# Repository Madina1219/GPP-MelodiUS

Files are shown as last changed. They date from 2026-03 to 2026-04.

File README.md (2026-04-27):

# MelodiUS

## Twin Piano Experience: An IoT-Connected Musical Instrument

**CASA0021: Group Prototype + Pitch**  
**Connected Environments - Group 6**  
**University College London (CASA) | 2025-2026**

| Team Member | Role |
|---|---|
| Madina Diallo | Project Manager |
| Xintong Shao | Enclosure Design and Aesthetics |
| Lizi Wang | Hardware & Software Developer |
| Ananya Jagadeesh Kedlaya | Software & Connectivity Lead |
| All Team Members | User Testing |

**GitHub repository:** <https://github.com/Madina1219/GPP-MelodiUS>  
**Word count:** approximately 2,000 words, excluding cover page, in-text citations and reference list  
**AI use statement:** AI tools were used to support structural review and refinement of phrasing. All technical content, design decisions, code, and analysis are the original work of the team.

---

## Abstract

MelodiUS is a pair of IoT-connected mini pianos designed to enable synchronised musical interaction between two users across any physical distance. When a key is pressed on Piano A, the corresponding key on Piano B lights up via LED feedback and plays the same note through I2S audio output, creating a mirrored experience in near real time. Communication is handled through MQTT over a local Wi-Fi network, with solenoid-based mechanical actuation identified as a future development path. This report documents the design rationale, technical development, iterative prototyping, and the broader Connected Environments context of the project, and outlines opportunities for further work.

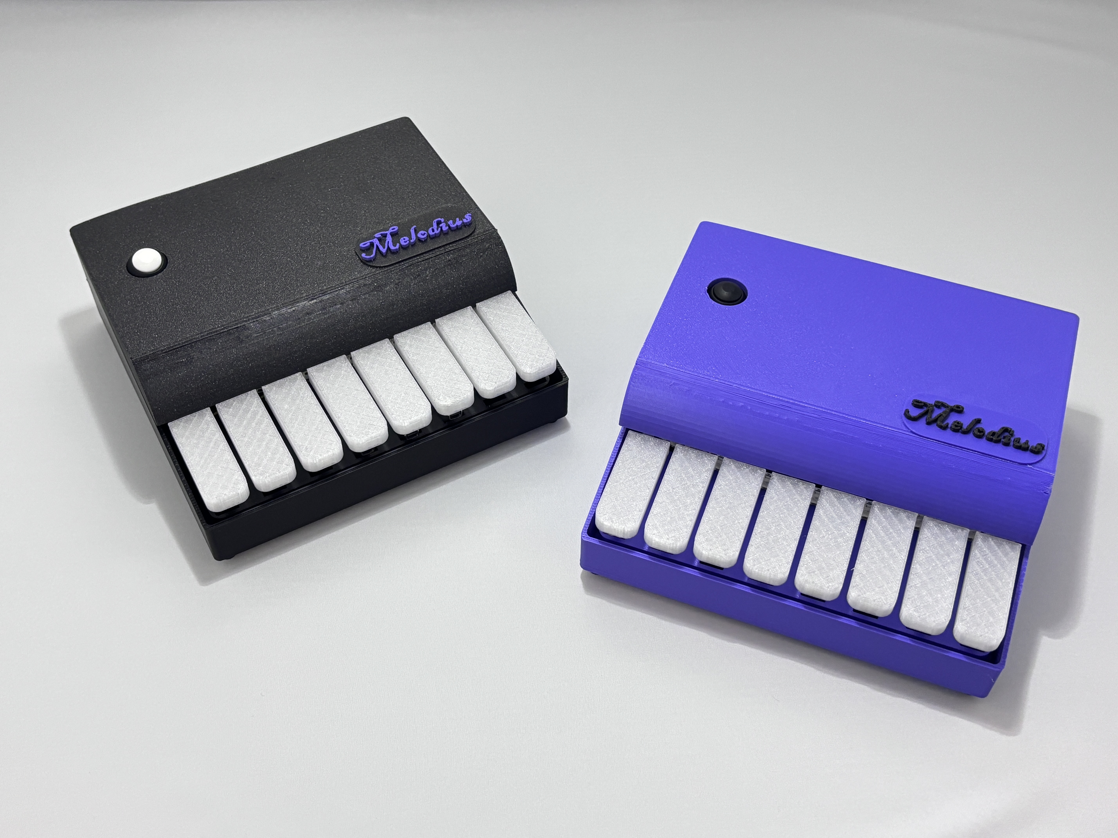
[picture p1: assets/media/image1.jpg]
Figure 1: The two finished MelodiUS units - a paired connected musical instrument.


*Figure 1: The two finished MelodiUS units - a paired connected musical instrument.*

---

## Table of Contents

- [1. Problem Identification and Motivation](#1-problem-identification-and-motivation)
  - [1.1 The Problem: Distance and Musical Connection](#11-the-problem-distance-and-musical-connection)
  - [1.2 Target Users and Scenarios](#12-target-users-and-scenarios)
  - [1.3 Context Within Connected Environments Research](#13-context-within-connected-environments-research)
- [2. Development of the Prototype and Design Iterations](#2-development-of-the-prototype-and-design-iterations)
  - [2.1 Initial Concept and Design Brief](#21-initial-concept-and-design-brief)
  - [2.2 Hardware Architecture](#22-hardware-architecture)
  - [2.3 Firmware Development](#23-firmware-development)
  - [2.4 Enclosure Design and Iterations](#24-enclosure-design-and-iterations)
  - [2.5 Connectivity and Software Stack](#25-connectivity-and-software-stack)
  - [2.6 User Testing and Evaluation](#26-user-testing-and-evaluation)
- [3. Production Cost and Sustainability](#3-production-cost-and-sustainability)
- [4. Future Improvements](#4-future-improvements)
- [5. Conclusion](#5-conclusion)
- [6. References](#6-references)

---

## 1. Problem Identification and Motivation

### 1.1 The Problem: Distance and Musical Connection

Music has long served as one of the most powerful vehicles for human connection. Yet remote work, long-distance relationships, and geographically distributed families mean that shared musical moments, playing together, learning together, or simply being present in the same musical space, are increasingly difficult to achieve. Existing solutions fall short. Video calls introduce audio-visual latency that makes synchronised playing practically impossible, while online music collaboration tools remain largely screen-based and disembodied, lacking the tactile presence of a shared instrument.

MelodiUS addresses this gap directly by exploring how two people, regardless of physical distance, can share the experience of playing an instrument together with genuine physical feedback and minimal latency, without requiring specialist audio infrastructure. The proposed answer is a pair of IoT-connected physical piano units that mirror key presses, LED responses, and, in future iterations, mechanical actuation in near real time using the MQTT messaging protocol over standard Wi-Fi.

### 1.2 Target Users and Scenarios

MelodiUS is designed for four user groups. First, distant families, for example, a grandparent playing a lullaby/nursery rhyme in Manchester while their grandchild hears every key press live in Paris. Second, couples in long-distance relationships who wish to share a nightly duet. Third, friends who grew up playing together but now live in different cities. Fourth, piano teachers and students, where a tutor in London can demonstrate fingering on a student's piano in Liverpool in real time, going beyond what screen sharing alone offers.

A central design decision was approachability. The pianos are compact, 3D-printed, and require no specialist technical knowledge: the user powers on the unit, connects to Wi-Fi through a captive web portal, and the two devices synchronise automatically through a shared MQTT broker. This deliberate simplicity lowers the barrier to entry while demonstrating sophisticated IoT connectivity underneath.

### 1.3 Context Within Connected Environments Research

MelodiUS sits within a rich lineage of research at the intersection of the Internet of Things, tangible computing, and human-computer interaction. Ishii and Ullmer (1997, pp. 234–241) argued that embedding computation in everyday objects produces more intuitive, embodied interaction; MelodiUS operationalises this principle directly, with the keys forming the interface and the LEDs and audio output forming tangible representations of networked data.

The project also draws on the calm technology tradition (Weiser and Brown, 1996, pp. 75–85), in which connected devices communicate peripherally without demanding sustained visual attention. Light and sound function here as ambient cues of remote presence rather than as primary information channels. The use of MQTT, a lightweight publish-subscribe protocol widely adopted in IoT deployments, is consistent with established practice for constrained networks (Banks and Gupta, 2014).

The project further aligns with affective computing, where connected devices mediate emotional states across distance rather than simply transmitting data (Picard, 1997). Within the specific domain of networked music performance (Rottondi et al., 2016), MelodiUS departs from high-fidelity audio streaming by transmitting discrete key-press events instead. This deliberate simplification reduces latency and hardware requirements while preserving the essence of shared musical play, positioning the project as a consumer-oriented interpretation of research-grade network music performance.

---

## 2. Development of the Prototype and Design Iterations

### 2.1 Initial Concept and Design Brief

The project responded to the Connected Places: Connected Ambient Devices Across the Miles brief, which required two independent yet linked devices capable of communicating information in a simple, glanceable, low-effort manner. Early ideation explored environmental sensing and community-based ambient systems, but the team identified an opportunity to reinterpret ambient connectivity through emotional, human-centred interaction. Music emerged as a uniquely powerful medium: it is universal, naturally expressive, and well-suited to glanceable, low-data communication.

The original vision involved full mechanical key actuation using solenoids to physically replicate remote presses. Component lead-times and the complexity of driving eight solenoids per device within a compact, battery-powered enclosure made this infeasible within the available timeframe. The team pivoted to LED feedback paired with I2S audio output, which preserves the core ambient experience of real-time perceptible connection while ensuring technical reliability. Solenoid actuation remains a defined future enhancement. The final brief settled on three requirements: near-zero perceived latency, accessible and reproducible components, and a high-quality physical form factor.

### 2.2 Hardware Architecture

Each device is built around an ESP32 microcontroller and integrates physical input, audio output, and visual feedback into a single self-contained unit. At the input layer, eight tactile push buttons are mapped to GPIO pins and represent the notes C4 to C5. Physical buttons were chosen over capacitive or screen-based alternatives because tactile feedback is fundamental to a musical interaction and lowers the barrier for non-expert users. At the output layer, audio is generated through an I2S interface driving a MAX98357A digital amplifier and a small speaker (Integrated Espressif Systems, 2024), which replaced an earlier piezo-buzzer prototype and substantially improved tonal clarity. Visual feedback is provided by a strip of WS2812 addressable LEDs, with two LEDs allocated per key and additional LEDs reserved for system states such as Wi-Fi connectivity and configuration mode, so that the device communicates its state without needing a screen.

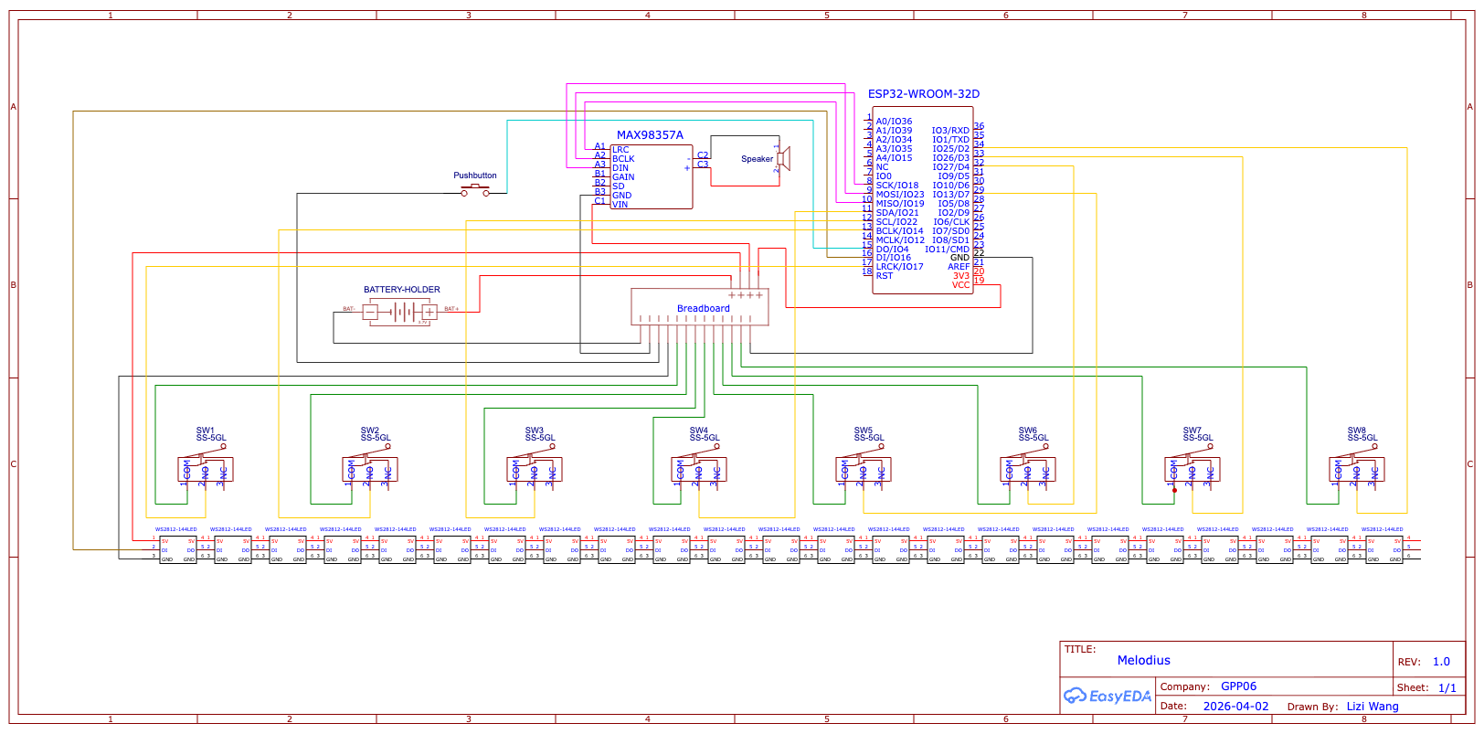
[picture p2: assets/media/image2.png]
Figure 2: Wiring diagram for a single MelodiUS unit.


*Figure 2: Wiring diagram for a single MelodiUS unit, showing ESP32, MAX98357A amplifier, push buttons, and the WS2812 LED strip.*

### 2.3 Firmware Development

Firmware development was highly iterative, illustrated in Figure 3. The first stage validated end-to-end interaction using a single key, confirming that the ESP32 could produce a perceptibly immediate response from physical input through to audio and LED output. Connectivity was then introduced through MQTT (Banks and Gupta, 2014). Rather than streaming audio, the system adopted an event-based protocol in which only key-press and key-release events are transmitted; each device reconstructs the corresponding sound and light locally. This event-driven choice was critical: it reduced bandwidth, removed the need for buffering, and made latency predictable.

The system was scaled to support all eight keys, with polyphony achieved by mixing real-time sine waves on the ESP32 (Smith, 2010). Finally, usability features were layered on top: a Wi-Fi access-point and captive web portal for first-time setup, a structured set of operational states (normal, configuration, sleep), and a deep-sleep routine that significantly improved battery life. Each iteration responded to a limitation observed in the previous one, allowing hardware, communication, and user experience to evolve in parallel.

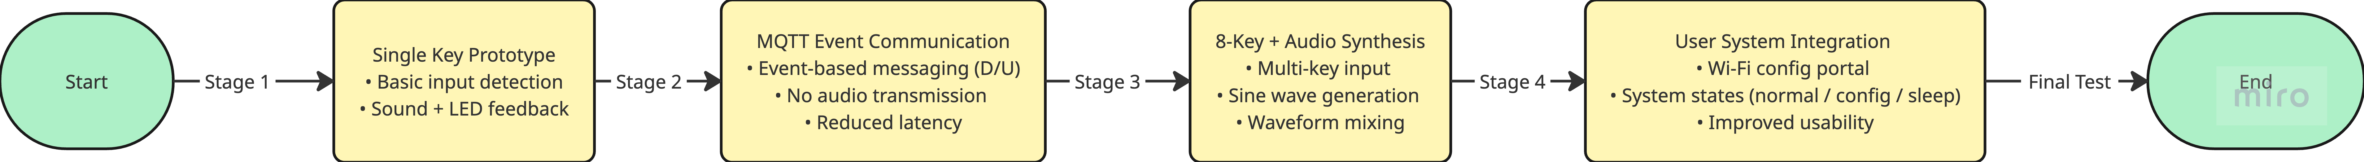
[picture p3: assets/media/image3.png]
Figure 3: Firmware evolution.


*Figure 3: Firmware evolution - from a single-key prototype, through MQTT event communication, to an eight-key polyphonic system with full user-state integration.*

### 2.4 Enclosure Design and Iterations

The enclosure was designed in Fusion 360 and 3D-printed, with three significant iterations driven by the relationships between form, manufacturability, internal layout, and usability (Weichel, Lau and Gellersen, 2013).

The first version verified the overall form, proportions, and rough internal volume. Once printed, the cavities were too tight for the wiring loom, the three top pillars intended to retain the keys were fragile and broke during installation, and the keys themselves were not properly constrained, allowing them to shift during play.

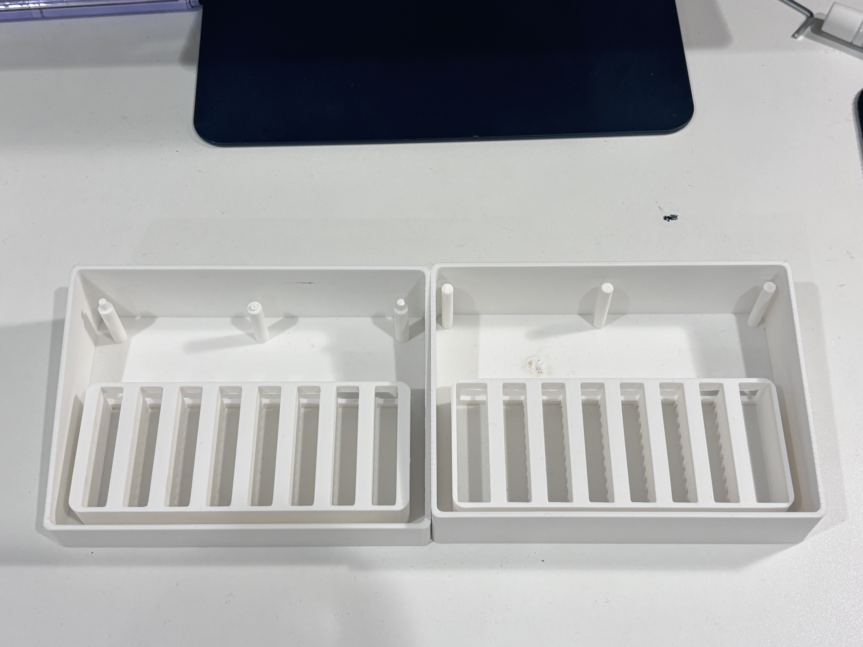
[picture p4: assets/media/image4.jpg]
Figure 4: First enclosure iteration.


*Figure 4: First enclosure iteration. Functional as a fit-check but cramped internally and structurally fragile around the key-retention pillars.*

The second version addressed these issues directly: internal volume was increased, the support pillars were widened, and dedicated holders were modelled for the ESP32 board, the battery, and the speaker. Each component now had a defined position, which simplified assembly and improved structural rigidity.

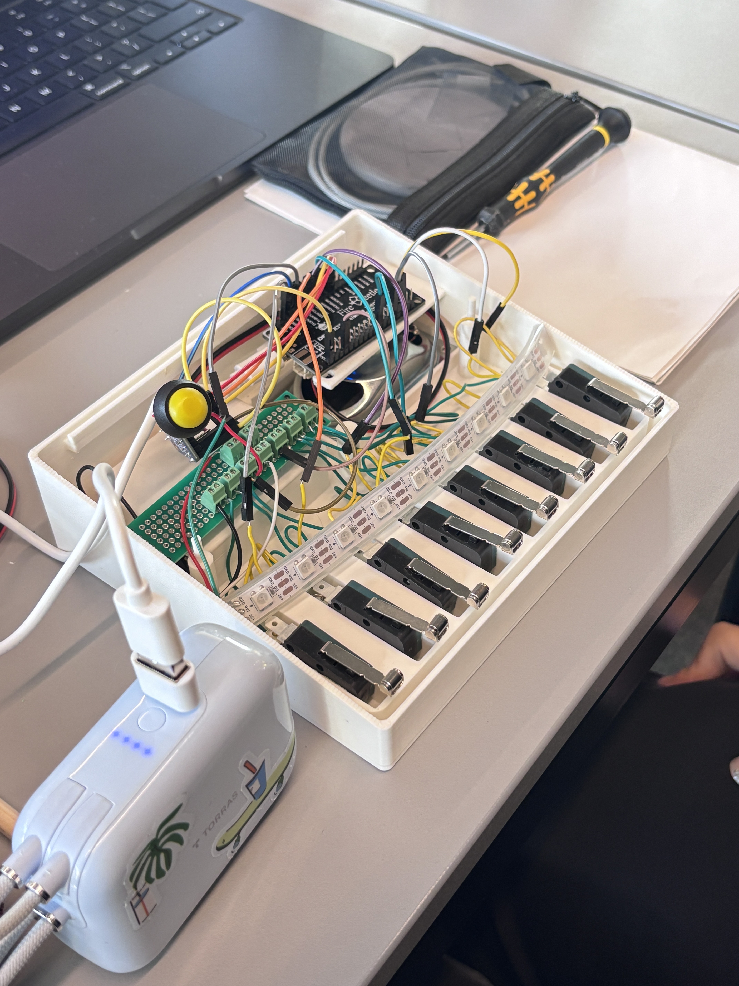
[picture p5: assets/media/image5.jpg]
Figure 5: Second enclosure iteration.


*Figure 5: Second enclosure iteration with widened pillars and dedicated component holders for the ESP32, battery, and speaker.*

The final version focused on material selection. The keys were changed from white PLA to transparent PETG so that the underlying WS2812 LEDs would illuminate the keys themselves, dramatically strengthening the visual feedback during play. A bespoke MelodiUS logo was designed and printed in a contrasting colour, and the enclosure was offered in coordinated black and purple finishes to give the product a recognisable identity and a more commercial finish.

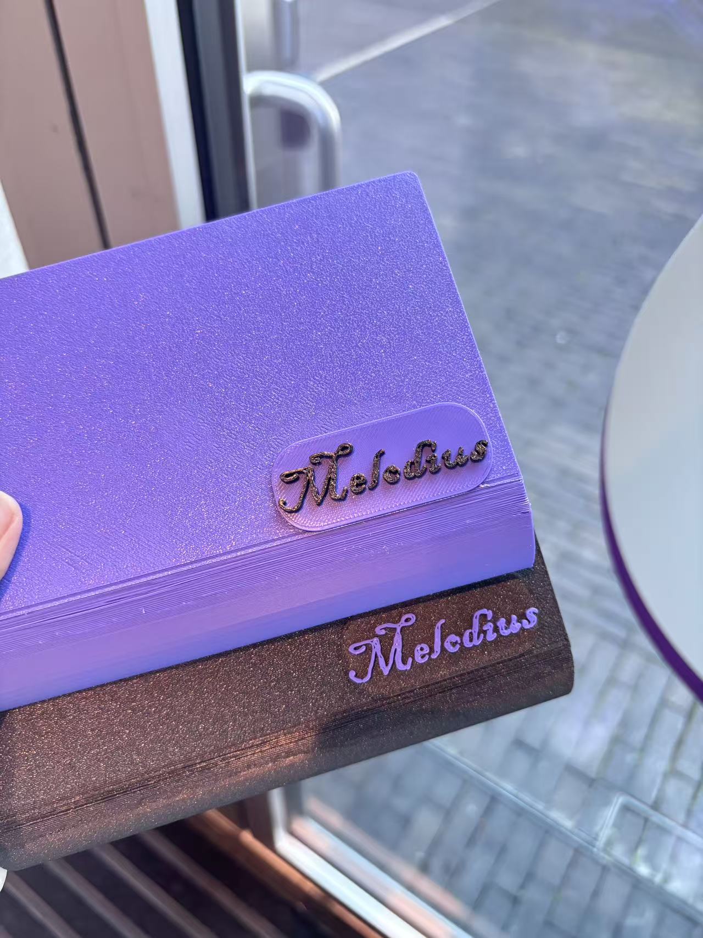
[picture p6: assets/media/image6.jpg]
Figure 6: Final enclosure detail.


*Figure 6: Final enclosure detail with custom MelodiUS logo, coordinated colourway, and matt textured finish.*

### 2.5 Connectivity and Software Stack

The system relies on a lightweight communication architecture in which two independent devices share a single MQTT broker over a local Wi-Fi network. Each key interaction is encoded as a minimal message containing the key index and a press or release flag. When a key is pressed, the device immediately produces local audio and LED feedback and simultaneously publishes the event; the other device, subscribed to the same topic, receives the message and reproduces the identical response. This event-based design avoids streaming and keeps round-trip latency low (Banks and Gupta, 2014).

The software is organised into clearly separated layers: a hardware layer for GPIO and I2S, a firmware layer for input handling, audio synthesis and LED control, a communication layer for MQTT, and a network layer for Wi-Fi management. The decoupling means that local responsiveness is not dependent on network conditions, and additional devices could in principle subscribe to the same topic without modification.

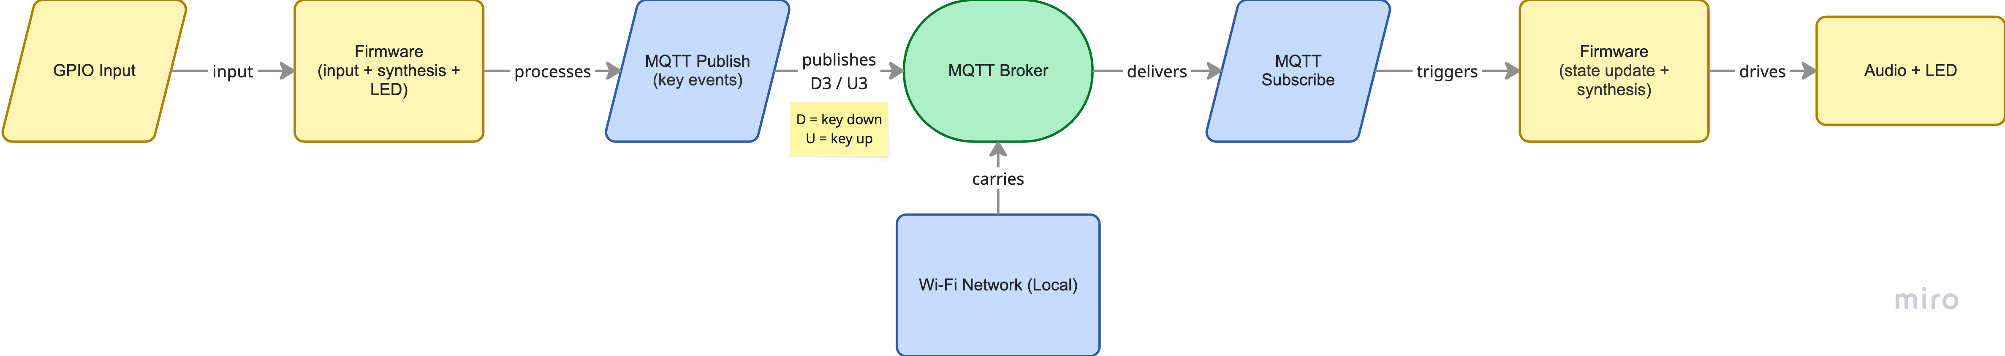
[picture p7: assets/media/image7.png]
Figure 7: System architecture.


*Figure 7: System architecture - GPIO input is processed locally and published as an MQTT event, then mirrored on the receiving device to drive identical audio and LED output.*

### 2.6 User Testing and Evaluation

- User Feedback: Testers quickly understood the LED feedback without guidance, found the audio response satisfying, and praised the refined physical design.
- Limitations: Restricted eight-key range and no velocity sensitivity.
- Functional Results: All key presses correctly triggered notes and LEDs on both devices. Latency over local Wi-Fi stayed under 500 ms, with reliable MQTT delivery.
- Iterations: Resolved Wi-Fi setup, power consumption, and false-trigger issues.
- Constraints: Tested on a single network; latency assessed perceptually.
---

## 3. Production Cost and Sustainability

**Table 1: Unit cost breakdown.**

| Component | Description | Cost (£) |
|---|---|---:|
| Hardware | ESP32 · keys · speaker · amplifier · LEDs · battery · misc. | 20-26 |
| Manufacturing | 3D-printed enclosure · assembly materials | 5-7 |
| Development | Software development · testing and iteration, amortised | 15 |
| Additional | Packaging · miscellaneous costs | 4 |
| **Total per unit** |  | **44-52** |

**Table 2: Funding and launch plan.**

| Item | Detail |
|---|---|
| Early-bird price, pair | £100 - 50% launch discount |
| Full commercial price, pair | £200 |
| Suggested retail, single | £79-99 |
| Profit margin | ~45% early bird; ~40-50% full commercial |
| Crowdfunding goal | £30,000 - covers solenoid upgrade and tooling |
| Initial batch | 200-300 units |
| Launch target | June 2026 |

Sustainability was considered at two levels. The PLA and PETG enclosure parts are biodegradable or recyclable, and the design uses standard, widely available components that can be repaired or replaced individually, avoiding the throwaway pattern of many connected consumer devices. Future revisions could replace the lithium-ion battery with a USB-C powered configuration or, as discussed in Section 4, integrate a small solar panel to reduce ongoing energy demand.

---

## 4. Future Improvements

Several improvements have been identified for future iterations of MelodiUS:

- Expanding the keyboard from eight to sixteen keys would significantly increase musical expressiveness. The MQTT protocol already supports arbitrary key indices, so the work is mostly mechanical and electrical.
- Velocity sensitivity could be added by using Hall-effect sensors with variable magnet distances, with the velocity value carried as an additional byte in the MQTT payload.
- The originally planned solenoid actuation would transform the device from a visually and aurally synchronised system into a genuinely haptic one. This requires a dedicated driver board, a more robust power supply, and careful mechanical alignment, but the emotional impact of physically moving keys would substantially strengthen the product.
- A companion mobile app could provide pairing, configuration, and a record-and-replay mode for remote teaching.
- Migrating from a local broker to a cloud-hosted MQTT broker secured with TLS and per-device authentication would extend the operating range from a single Wi-Fi network to genuinely global distances.
- Mechanical refinement (rubberised key dampers to soften the click) and energy refinement (a solar-charged battery option) would further improve the experience and sustainability profile of the product.
A couple of small things to double-check when you paste it in:

---

## 5. Conclusion

MelodiUS demonstrates that ambient, emotionally meaningful connection between distant people can be delivered through small, accessible, well-finished hardware. By transmitting discrete events rather than audio streams, the project achieves perceptibly real-time mirroring of musical play between two ESP32-based devices using nothing more than a Wi-Fi network and an MQTT broker. The iterative development process, moving from a single-key proof of concept, through firmware scaling and three enclosure revisions, to a finished pair of branded units, produced a prototype that is reliable, reproducible, and ready for further development. While limitations remain in keyboard range, expressive nuance, and operating range, each is addressed by a clearly scoped path of future work. The result is a connected musical instrument that treats distance not as an obstacle to be overcome with higher bandwidth, but as a context in which simple, well-designed signals can carry presence, intention, and shared joy.

---

## 6. References

- Banks, A. and Gupta, R. (2014) *MQTT Version 3.1.1*. OASIS Standard. Available at: <https://www.oasis-open.org/standard/mqttv3-1-1/> (Accessed: 15 April 2026).
- Espressif Systems (2024) *ESP32 Technical Reference Manual: Inter-IC Sound (I2S)*. Available at: <https://docs.espressif.com/projects/esp-idf/en/release-v4.4/esp32/api-reference/peripherals/i2s.html> (Accessed: 15 April 2026).
- HiveMQ (2023) *MQTT Essentials: A Lightweight Messaging Protocol for IoT*. Available at: <https://www.hivemq.com/mqtt-essentials/> (Accessed: 15 April 2026).
- Ishii, H. and Ullmer, B. (1997) 'Tangible bits: towards seamless interfaces between people, bits and atoms', *Proceedings of the SIGCHI Conference on Human Factors in Computing Systems*, pp. 234-241. Available at: <https://doi.org/10.1145/258549.258715>.(Accessed: 15 April 2026).
- Picard, R.W. (1997) *Affective Computing*. Cambridge, MA: MIT Press.
- Rottondi, C., Chafe, C., Allocchio, C. and Sarti, A. (2016) 'An overview on networked music performance technology', *IEEE Access*, 4, pp. 8823-8843. Available at: <https://doi.org/10.1109/ACCESS.2016.2628440>.
- Smith, J.O. (2010) *Physical Audio Signal Processing*. W3K Publishing. Available at: <https://ccrma.stanford.edu/~jos/pasp/> (Accessed: 15 April 2026).
- Weichel, C., Lau, M. and Gellersen, H. (2013) 'Enclosed: A component-centric interface for designing prototype enclosures', *Proceedings of the 7th International Conference on Tangible, Embedded and Embodied Interaction*, pp. 215-218. Available at: <https://doi.org/10.1145/2460625.2460659> (Accessed: 3 April 2026).
- Weiser, M. and Brown, J.S. (1996) 'Designing calm technology', *PowerGrid Journal*, 1(1), pp. 75-85. Available at: <https://calmtech.com/papers/designing-calm-technology>.(Accessed: 4 April 2026).

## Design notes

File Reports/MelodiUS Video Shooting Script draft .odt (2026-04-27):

Simple MelodiUS Video Shooting Script (90 seconds)

1. Scene 1 - Distance / Opening – Music note travelling around those areas
a. Film a busy London street / train / Airport / Campus or Westfield area (time-lapse or slow pan). (6 sec)
b. Cut to a different place (park, café, or another room). (6 sec)

Text on screen: “Distance changes everything.” (Soft piano music starts, no voiceover)

2. Scene 2 - The Problem -Music note travelling lands on a piano key
a. Person sitting alone at a piano thinking or looking at the keys. (4 sec)
b. Show another piano with no one sitting there (empty seat). (4 sec)

Text on screen: “What if distance didn’t stop you playing together?” (Silence or soft music, no voiceover)

3. Scene 3 - Product Reveal
a. Close-up of a finger pressing one piano key. (5 sec)
b. Cut to the second piano key moving or lighting up. (5sec)

Voiceover (short): “When one key is pressed here… the same key moves there.”

4. Scene 4 - Demonstration (Most Important)
a. Split screen: Piano A and Piano B side-by-side. (10 sec)
b. Show keys moving at the same time. (7 sec)
c. Show hands playing both pianos in sync. (8 sec)

Show reaction shots (smiles, surprise, excitement). (Very little talking, we let the visuals show it)

5. Scene 5 - Team
a. Each team member appears interacting with the device, not posing (3 sec each)

Text: Name + role (e.g., Madina, Project coordinator) (Music only, no talking)

6. Scene 6 - Why It Matters
a. parent and child playing (smiling when keys are moving) (3 sec)
b. friends playing together remotely. (smiling when keys are moving) (3 sec)
c. Lovers playing (smiling when keys are moving) (3 sec)

Voiceover: “Whether across a city or across the world, MelodiUS brings people together.”

7. Scene 7 - Future Vision / Ending
a. Close-up of the prototype, beautifully lit. Slow fade to black (4 sec)
b. Future Version with Solenoid (4 sec)

Final text: “MelodiUS, Feel the Distance Disappear.”

Total video: 90 seconds

Clips: 3–10 seconds each

Goal: Someone should understand the idea even without voiceover.

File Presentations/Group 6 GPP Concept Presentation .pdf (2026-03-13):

# Melodius

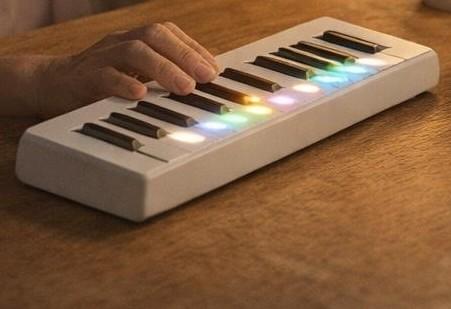
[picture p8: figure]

Group 6-GPP

## Twin Piano Experience

Connecting through Music

# What is Melodius?

### A revolutionary way to connect through

synchronized music anytime, anywhere.

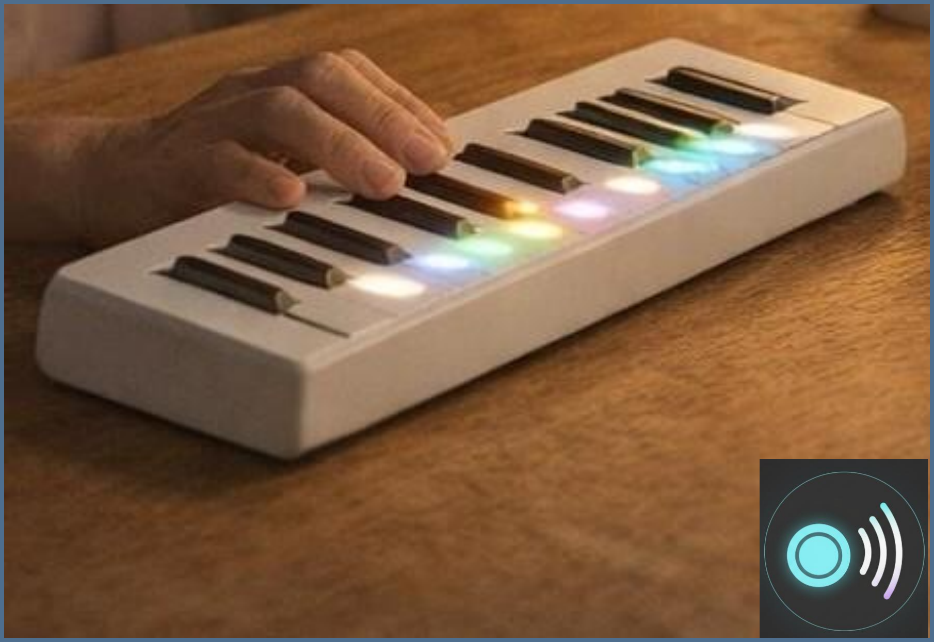
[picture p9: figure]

MelodiUS connects people through sound.
Music is a powerful way to express emotion without relying on words. Through music, MelodiUS brings people together across distance, time, and place.
It creates shared musical experiences by letting people communicate and bond through melodies made for one another.

# Why a Piano?

The piano is a widely loved instrument. However, meaningful musical experiences have traditionally required people to be physically together.
Melodius reimagines the piano as a collaborative instrument. It enables people to play, share and create music together, whether they are nearby or far apart. This opens the door to shared melodies, remote jam sessions and bonding without distance restriction.

# Primary Target Users?

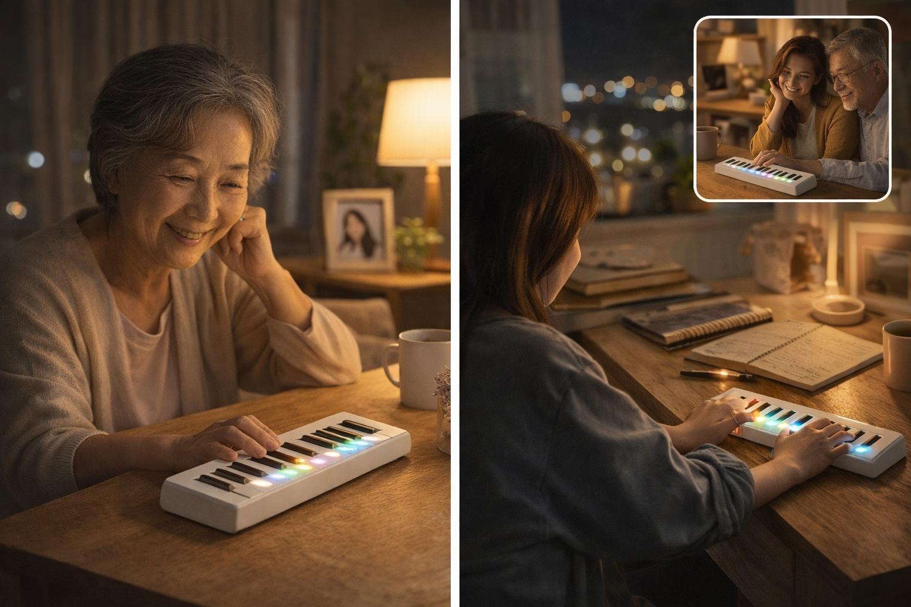
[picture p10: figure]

A shared musical experience across miles, connecting people.

## User Personas:

Beloved ones
- Friends
- Families
- Couples

# Research

1. Most current remote music tools (e.g. video calls, collaborative DAWs) rely on screen-based, cognitively demanding interaction. Melodius improves on this by offering co-temporal, embodied sound-making, which fosters emotional closeness without requiring language or attention-heavy interfaces (Tarr, B., Launay, J. and Dunbar, R. (2014).
2. Existing connected devices often treat each object as autonomous, leading to turn-taking rather than true collaboration. Melodius improves on this by maintaining a shared musical state (timing, rhythm, scale), enabling both users to act within the same sonic space (Dourish, P. (2001).
3. Streaming audio across long distances is highly sensitive to network latency and packet loss, which degrades musical experience. Twin Piano addresses this limitation by transmitting lightweight event data (key pressed, timing, velocity), which significantly reduces bandwidth and improves robustness (Al-Fuqaha, A. et al. (2015).
4. How Sound Connects Us - https://mnartists.walkerart.org/resonating-relating-how-sound-connects-us Emily Dzieweczynski, Resonating/Relating:
5. How Humans Communicate Through Sound : Kraus, Nina, Slater, Jessica, Beyond Words:

Melodius builds on research in social bonding, embodied interaction, and IoT system design by combining synchronous music-making, to create a shared sense of presence across distance.

# How It Works

KEY PRESS

When a user presses a key on Piano A, the sensor immediately detects the action and prepares for signal transmission.

SIGNAL DETECTION

The sensor sends a signal via the IoT module, ensuring real-time communication and connection with the counterpart piano across distances.

INSTANT PLAYBACK

The signal reaches Piano B, lighting up the corresponding key, activating movement, and producing sound simultaneously, creating a synchronized experience.

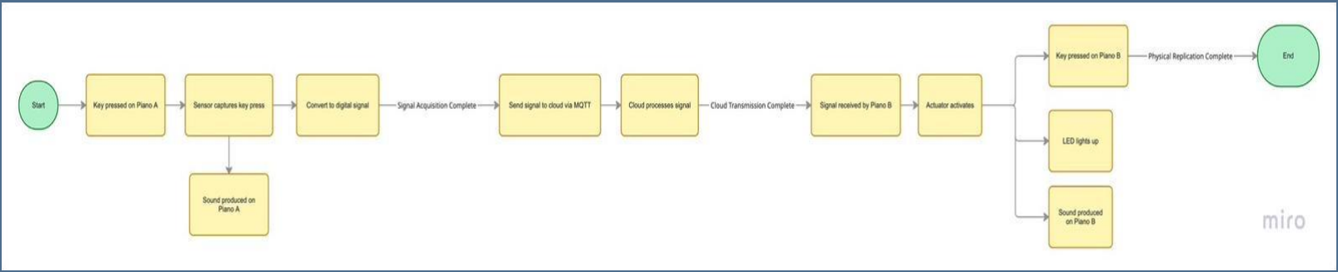
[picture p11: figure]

# Technology Components Hardware

Mini Keys

Sensitive keys for
interactive musical
input and expressive
play

Led Lighting

Integrated LEDs provide
real-time visual
feedback for key presses
and synchronization

The Melodius piano utilizes microcontrollers, sensors, and LEDs to ensure precise key detection and synchronized lighting effects during play.

Microcontrollers with
Wifi

ESP32 (or similar)
enables key detection,
processing, and wireless
communication
between devices.

Servos

Used to mirror
physical key
movement on the
paired piano for
enhanced
synchronisation

Sensors

RFI-resistant
touch sensor
detect key presses
and interaction
intensity

# Technology Components Software

Real-time messaging protocols manage data transmission between pianos, enabling seamless synchronization despite varying internet conditions and minimizing latency challenges.

Microcontroller
Code

Handles key
detection, LED
control, and
communication
logic on each
device

Wireless
Communication
Protocol

Wifi or MQTT to
enable low-latency
transmission of
key events
between pianos.

Synchronization
Logic

Ensures key
presses, timing,
and lighting
remain aligned
across both
devices

Power & State
Management

Controls sleep
modes, connectivity
states, and efficient
battery usage

Sound Generation
Module

Maps key inputs to
musical notes and
produces local audio
playback

# High Level Project Timeline

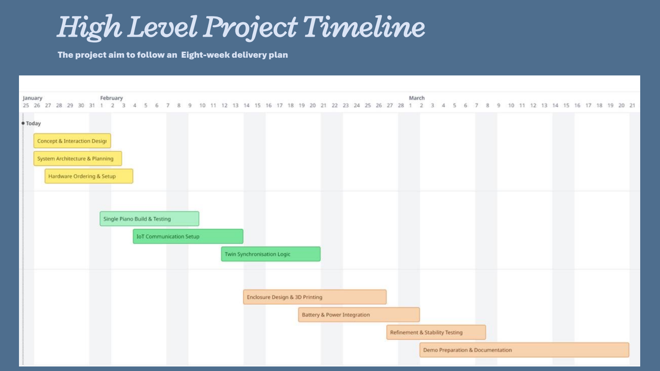
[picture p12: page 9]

The project aim to follow an Eight-week delivery plan

# Next steps and current challenges

Current Challenges
- Network latency may affect real-time key synchronisation.
- Mechanical or sensor-based key detection requires careful calibration.
- Battery life is limited when using Wi-Fi, LEDs, and sound together.
- Balancing simplicity for non-musicians with expressive musical interaction.
- Ensuring reliable touch input without false triggers from electrical noise.
- Physical enclosure constraints limit component placement and heat dissipation.

Next Steps
- Optimise data transmission using lightweight, event-based messaging.
- Refine key sensitivity and LED feedback for clearer interaction.
- Improve power management through sleep modes and efficient components.
- Conduct small-scale user testing to evaluate emotional engagement.
- Iterate enclosure design for ergonomics and durability.
- Documentation

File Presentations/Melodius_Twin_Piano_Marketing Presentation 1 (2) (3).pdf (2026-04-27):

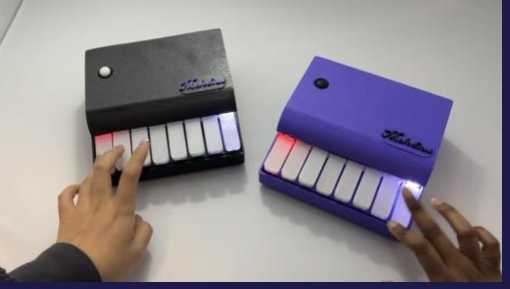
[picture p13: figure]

M E L O D I U S | T W I N | P I A N O

Play Together.
Feel Together.

## Connecting hearts across miles through the magic of music

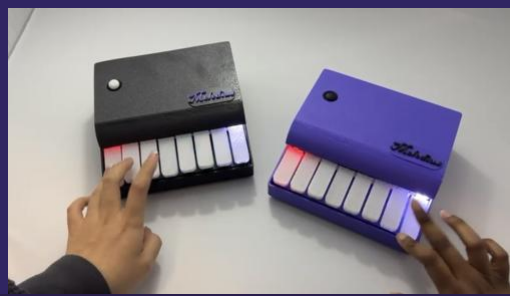
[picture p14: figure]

GPP - Prototype Presentation - CASA UCL 2026

# Feel Every Note, No Matter the Distance

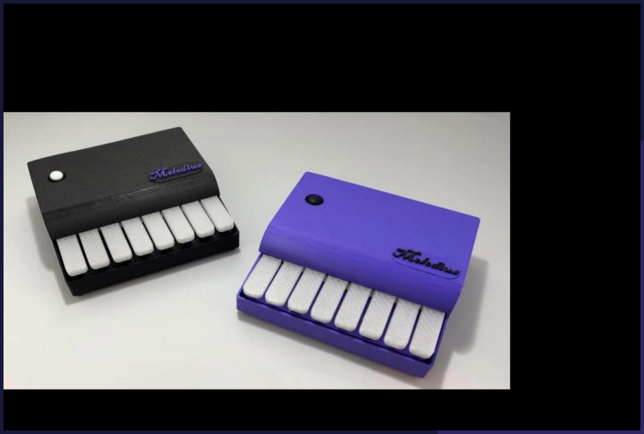
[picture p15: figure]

GPP - Prototype Presentation - CASA UCL 2026

# https://youtu.be/LaLsGw5UT-Q

## Lizi Wang

## Ananya Jagadeesh Kedlaya

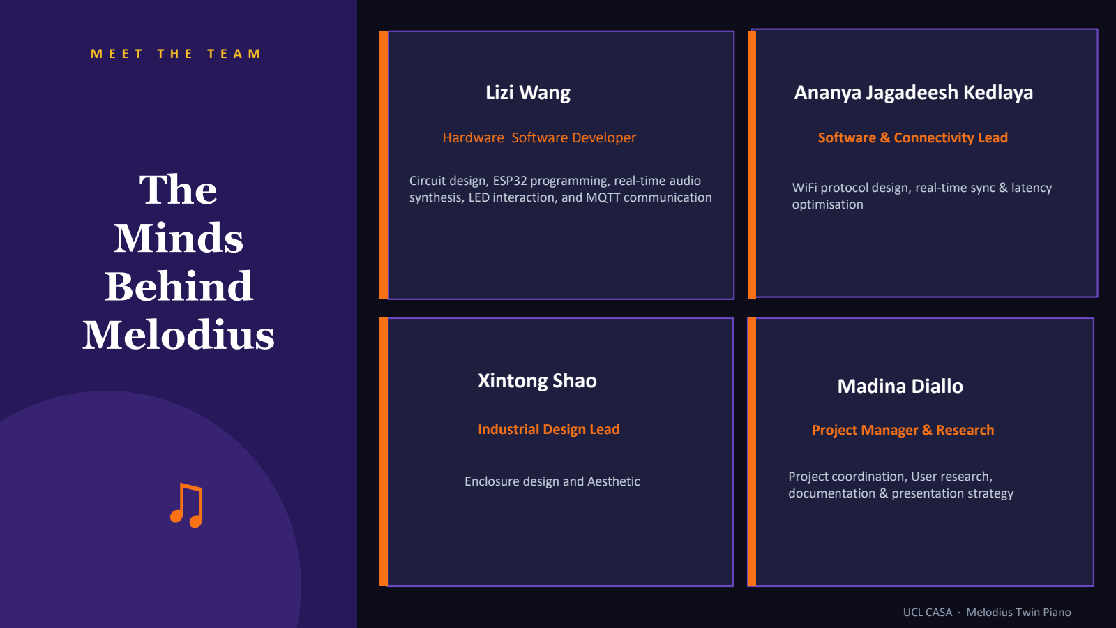
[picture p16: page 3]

M E E T T H E T E A M

# The Minds Behind Melodius

♫

Hardware Software Developer

Circuit design, ESP32 programming, real-time audio synthesis, LED interaction, and MQTT communication

Software & Connectivity Lead

WiFi protocol design, real-time sync & latency optimisation

## Xintong Shao

Industrial Design Lead

Enclosure design and Aesthetic

## Madina Diallo

Project Manager & Research

Project coordination, User research, documentation & presentation strategy

UCL CASA · Melodius Twin Piano

T H E | C H A L L E N G E | W E | S O L V E

# Music Connects Us - Distance Shouldn't Stop That

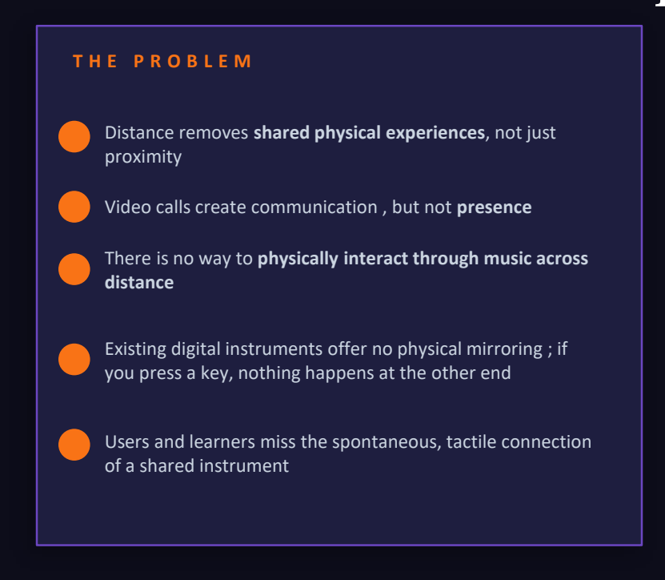
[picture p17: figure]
proximity; of a shared instrument; distance

Distance removes shared physical experiences, not just

Video calls create communication , but not presence

Existing digital instruments offer no physical mirroring ; if you press a key, nothing happens at the other end

Users and learners miss the spontaneous, tactile connection

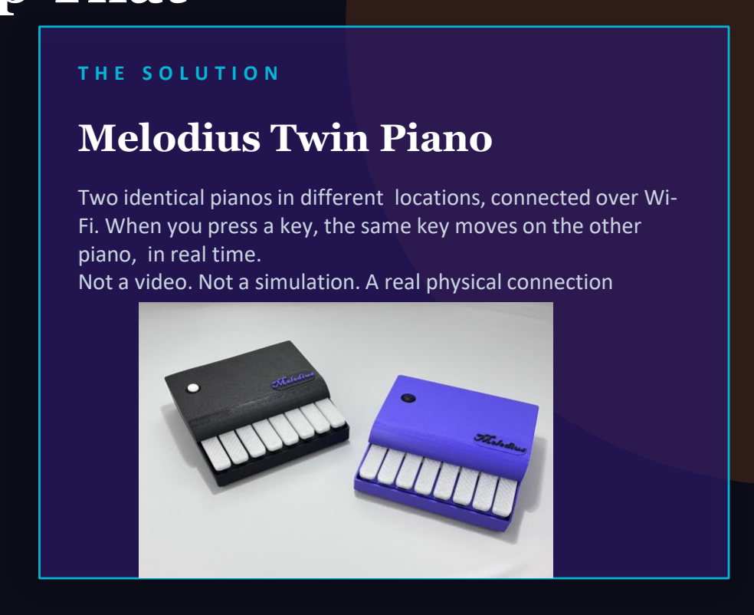
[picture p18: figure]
Melodius Twin Piano; piano, in real time.

### Two identical pianos in different locations, connected over Wi-Fi. When you press a key, the same key moves on the other

### Not a video. Not a simulation. A real physical connection

There is no way to physically interact through music across

W H Y | M E L O D I U S | S T A N D S | O U T

# Unique Selling Points

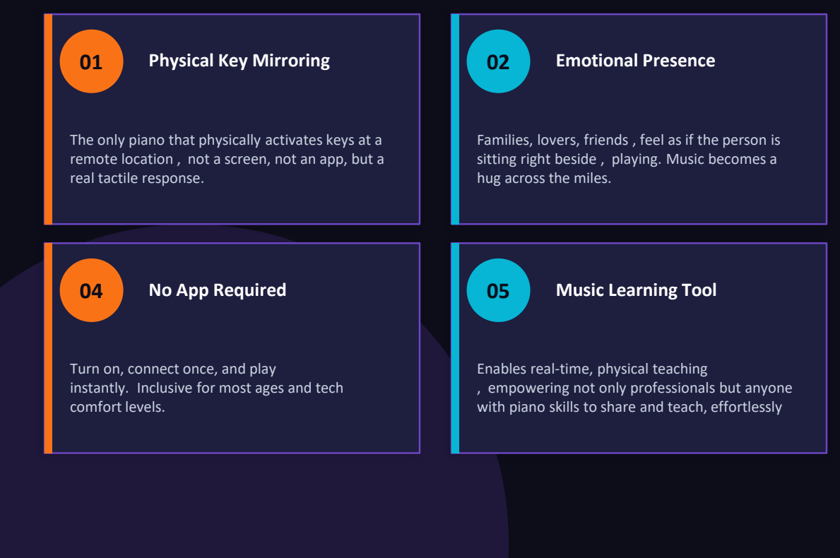
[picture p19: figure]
01 Physical Key Mirroring; real tactile response.; 02 Emotional Presence; hug across the miles.; 04 No App Required; Turn on, connect once, and play; comfort levels.; 05 Music Learning Tool; Enables real-time, physical teaching

The only piano that physically activates keys at a remote location , not a screen, not an app, but a

Families, lovers, friends , feel as if the person is sitting right beside , playing. Music becomes a

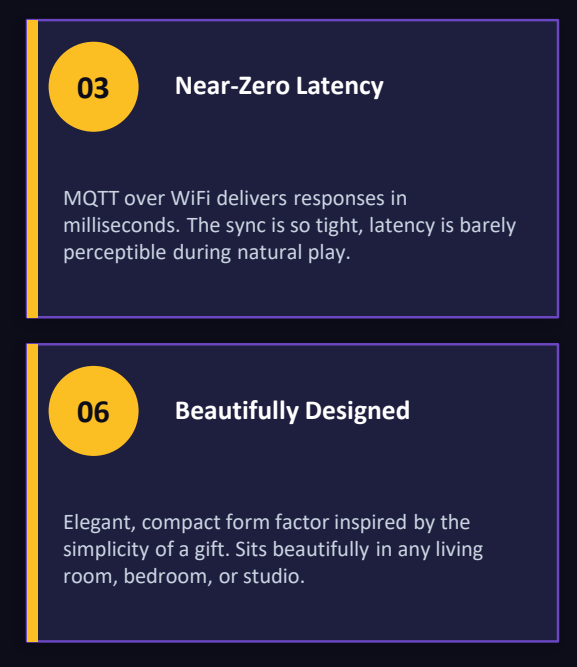
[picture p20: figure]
03 Near-Zero Latency; MQTT over WiFi delivers responses in; perceptible during natural play.; 06 Beautifully Designed; room, bedroom, or studio.

milliseconds. The sync is so tight, latency is barely

instantly. Inclusive for most ages and tech

, empowering not only professionals but anyone with piano skills to share and teach, effortlessly

Elegant, compact form factor inspired by the simplicity of a gift. Sits beautifully in any living

# Target Users & Scenarios

28M+

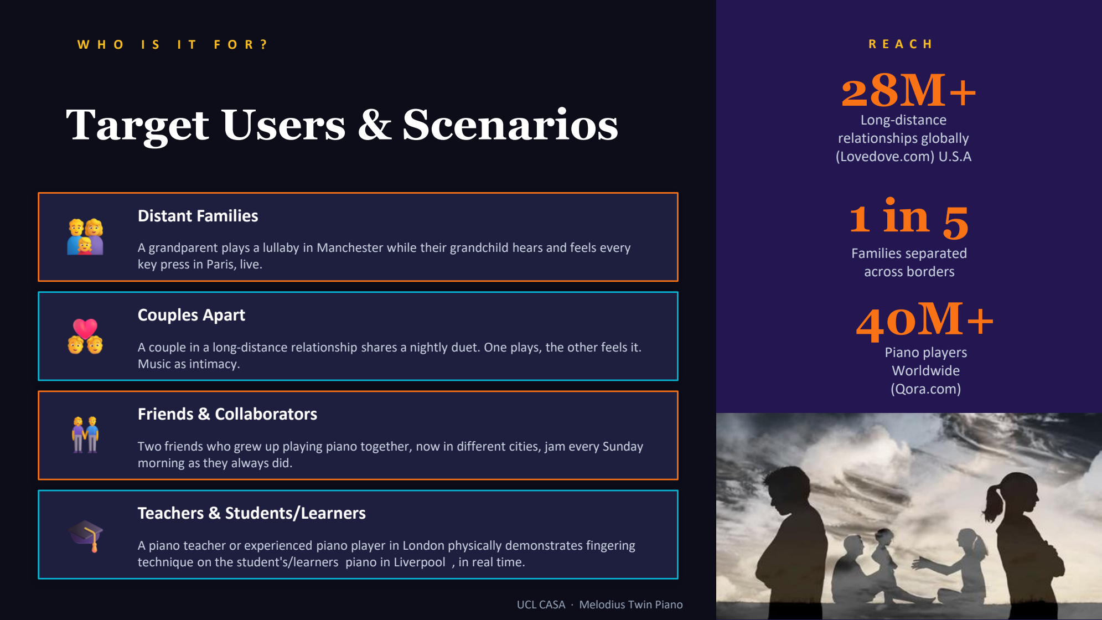
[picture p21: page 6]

W H O | I S | I T | F O R ?

## Distant Families

A grandparent plays a lullaby in Manchester while their grandchild hears and feels every key press in Paris, live.

## Couples Apart

A couple in a long-distance relationship shares a nightly duet. One plays, the other feels it. Music as intimacy.

## Friends & Collaborators

Two friends who grew up playing piano together, now in different cities, jam every Sunday morning as they always did.

## Teachers & Students/Learners

A piano teacher or experienced piano player in London physically demonstrates fingering technique on the student's/learners piano in Liverpool , in real time.

R E A C H

Long-distance
relationships globally
(Lovedove.com) U.S.A

# 1 in 5

Families separated
across borders
40M+

Piano players
Worldwide
(Qora.com)

# How the MelodiUs Twin Piano Works

1

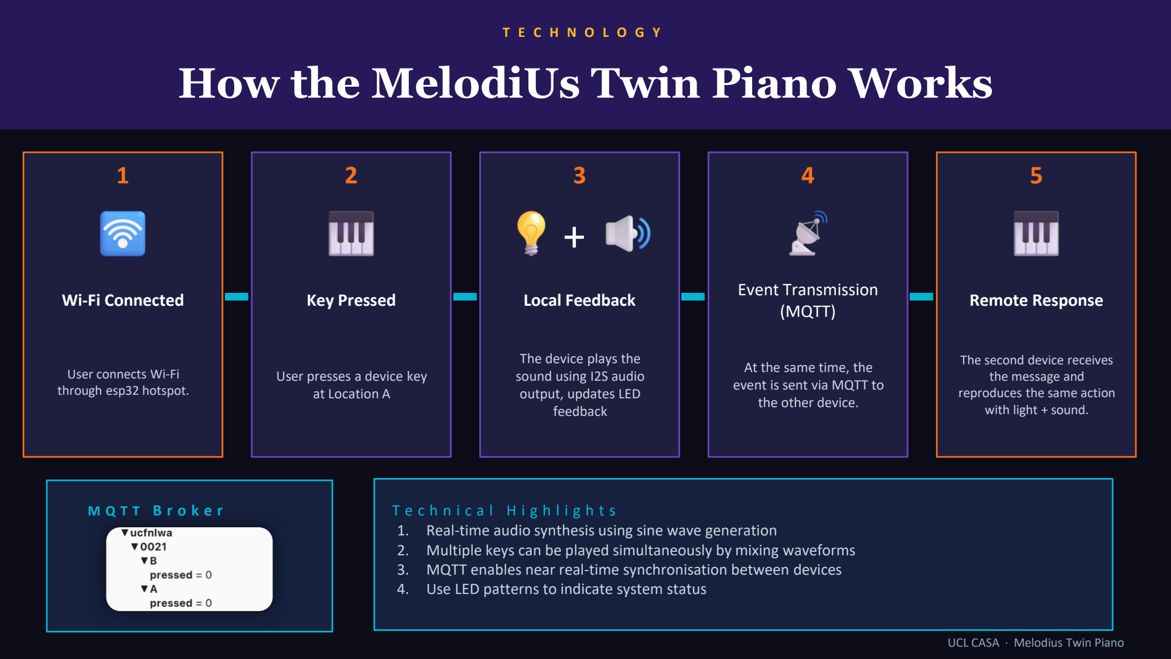
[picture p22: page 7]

T E C H N O L O G Y

### Wi-Fi Connected

User connects Wi-Fi
through esp32 hotspot.

›

2

### Key Pressed

User presses a device key
at Location A

›

3
+

### Local Feedback

The device plays the
sound using I2S audio
output, updates LED
feedback

›

4

### Event Transmission (MQTT)

At the same time, the
event is sent via MQTT to
the other device.

›

5

### Remote Response

The second device receives the message and
reproduces the same action with light + sound.

M Q T T B r o k e r

T e c h n i c a l H i g h l i g h t s
1. Real-time audio synthesis using sine wave generation
2. Multiple keys can be played simultaneously by mixing waveforms
3. MQTT enables near real-time synchronisation between devices
4. Use LED patterns to indicate system status

# Prototyping Journey

## 01 Concept & Research

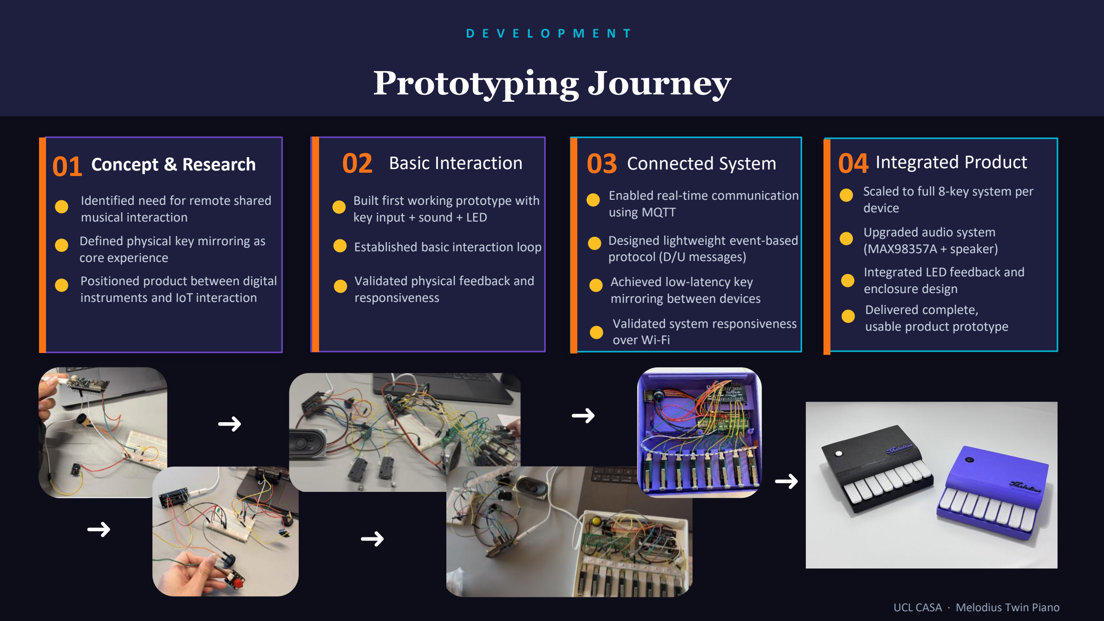
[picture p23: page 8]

D E V E L O P M E N T

Identified need for remote shared musical interaction

## 02 Basic Interaction

Built first working prototype with key input + sound + LED

Established basic interaction loop

Validated physical feedback and responsiveness

## 03 Connected System

Validated system responsiveness over Wi-Fi

## 04 Integrated Product

Enabled real-time communication using MQTT

Designed lightweight event-based protocol (D/U messages)

Achieved low-latency key
mirroring between devices
Delivered complete,
usable product prototype

Scaled to full 8-key system per device

Upgraded audio system
(MAX98357A + speaker)
Integrated LED feedback and enclosure design

Defined physical key mirroring as core experience
Positioned product between digital instruments and IoT interaction

➜

➜

➜

➜

➜

# What We Built & How It Performs

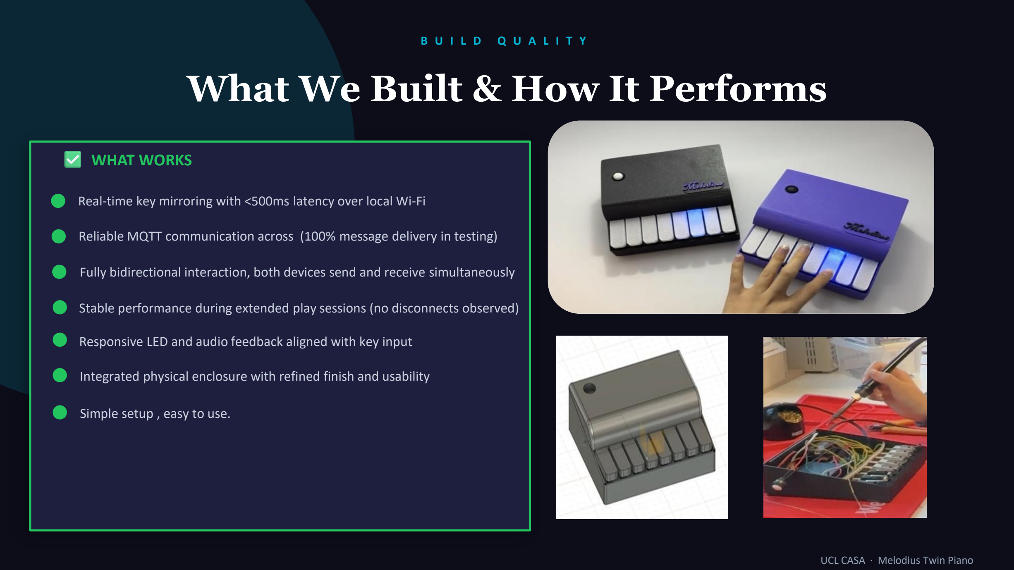
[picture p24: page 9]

B U I L D Q U A L I T Y

## WHAT WORKS

Real-time key mirroring with <500ms latency over local Wi-Fi

Reliable MQTT communication across (100% message delivery in testing)

Fully bidirectional interaction, both devices send and receive simultaneously

Stable performance during extended play sessions (no disconnects observed)

Responsive LED and audio feedback aligned with key input

Integrated physical enclosure with refined finish and usability

Simple setup , easy to use.

A S S E S S M E N T

# Current Limitations & Challenges

Internet Distance Latency

Over local Wi-Fi, latency is almost unnoticeable, enabling smooth real-time interaction. However, when connecting across long distances (e.g. London to China), network latency can introduce slight delays in synchronisation. This reflects a fundamental constraint of internet infrastructure, which we are actively working to optimise.

Mechanical Actuation Fidelity

Current servo motors enable functional key movement but do not yet replicate the full expressive dynamics of an acoustic piano. Variations in touch, such as forte and pianissimo, are limited in this prototype and will be enhanced in Phase 2.

Scale Limitation (8 Keys)

This prototype covers 8 keys , sufficient for basic melodies but falling short of a full key instrument. Scaling up requires additional expansion boards and motor channels.

Power & Portability

The current product is powered by basic batteries. For improved sustainability and longer usage, future versions will incorporate rechargeable battery systems. This will enable greater portability, allowing the product to be easily used across different rooms or in travel settings.

Wi-Fi Dependency

Both units require a stable WiFi connection. Weak or congested networks can introduce jitter. A dedicated pairing mode with QoS (Quality of Service) settings is planned.

Initial device Setup Experience for Non-Tech Users

The current onboarding process involves manual connection to the ESP32 Wi-Fi interface and configuration of network and MQTT settings. To enhance user experience, future iterations will introduce frictionless one-tap pairing via NFC or QR codes.

W H A T | C O M E S | N E X T

# Future Phases & Development Roadmap

## PHASE 2 - SOLENOID MOTOR UPGRADE

- Elaborate on the initial prototype of using solenoids with hall effect sensor to capture keynote pressed and mimic the same mechanism over the miles.
- Enhance look and feel of the piano design. Test various enclosures with smooth finishing and a clean aesthetic. S
- Solenoids deliver sharper, faster strikes with full velocity sensitivity, eliminating mechanical latency and creating an experience truly indistinguishable from a person playing in the room. This is the single most impactful upgrade for Phase 2.

### P2 Solenoid Mechanical Sync

Solenoid motors replacing push buttons

12 keys instrument scale

Velocity-sensitive actuation

Sub-5ms actuation response

### P3 Network & Latency Refinement

Cloud MQTT with QoS Level 2

Adaptive buffering for long distances

Dedicated Melodius pairing app

End-to-end encrypted session keys

### P4 Product & Design Polish

Premium wood enclosure options

NFC one-tap pairing

Companion mobile app

Gift set packaging for couples

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

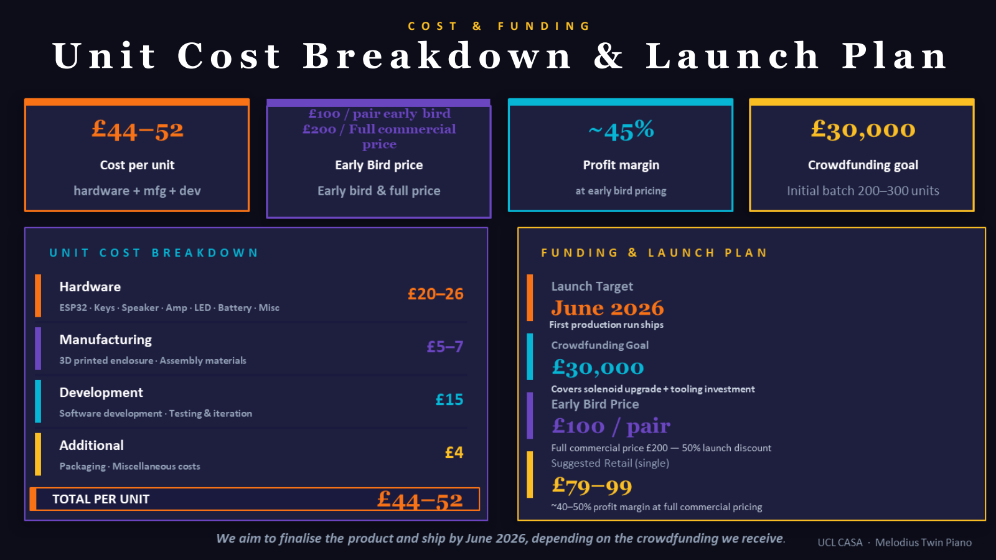
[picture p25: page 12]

C O S T | & | F U N D I N G

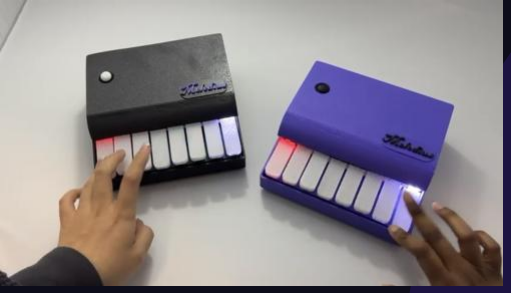
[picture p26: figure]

♫

Play Together.
Feel Together.

## @melodiuspiano

# Thank you - Q&A

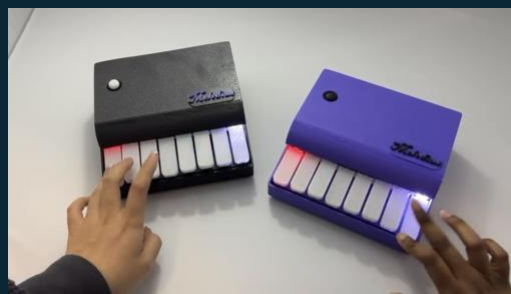
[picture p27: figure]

UCL CASA · Prototype Presentation · 2026

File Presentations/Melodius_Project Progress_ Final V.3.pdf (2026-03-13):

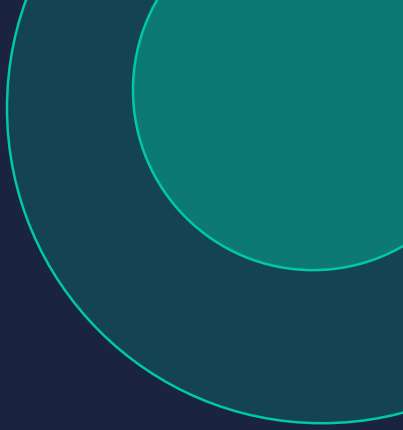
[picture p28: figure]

# M E L O D I U S

# Twin Piano Experience

Progress Presentation · Group 6 GPP

PROTOTYPE PHASE

1. Prototype Demo | 2. Target Users | 3. Challenges & Plan B | 4. Next Steps

# WHERE WE ARE NOW and Prototype Demo A

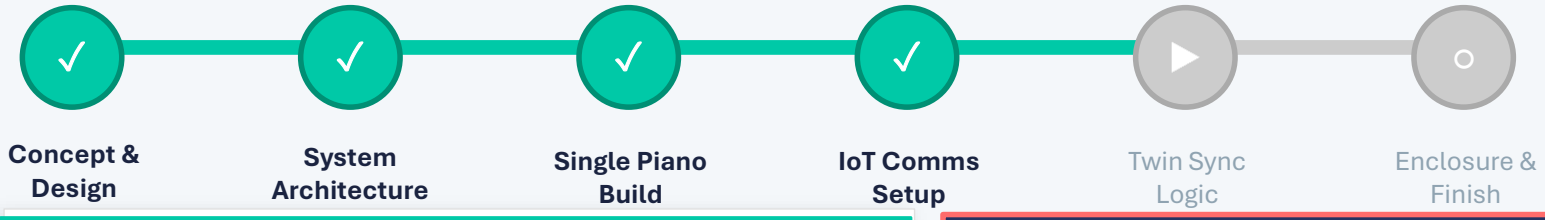
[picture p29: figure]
Concept & Design; System Architecture; Single Piano Build; IoT Comms Setup; Twin Sync Logic; Enclosure & Finish
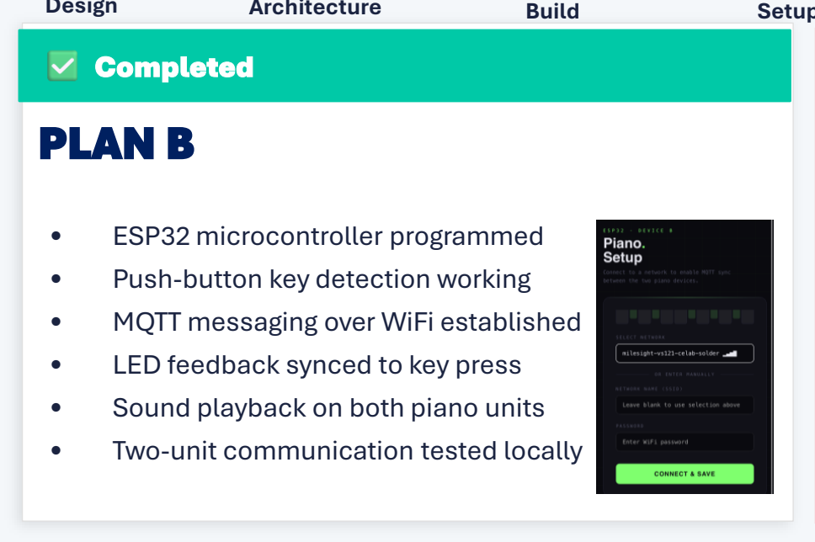
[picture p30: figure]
Completed; • ESP32 microcontroller programmed • Push-button key detection working • MQTT messaging over WiFi established • LED feedback synced to key press • Sound playback on both piano units • Two-unit communication tested locally; PLAN B

Stable & Working

LED + Sound Synchronisation

- MQTT event triggers LED glow on matching key
- Audio plays instantly on receiving piano
- Lower power, more robust over internet
- Visually intuitive , light guides the experience
- Ready for demo if solenoid not resolved in time

# WHERE WE ARE NOW and Prototype Demo B

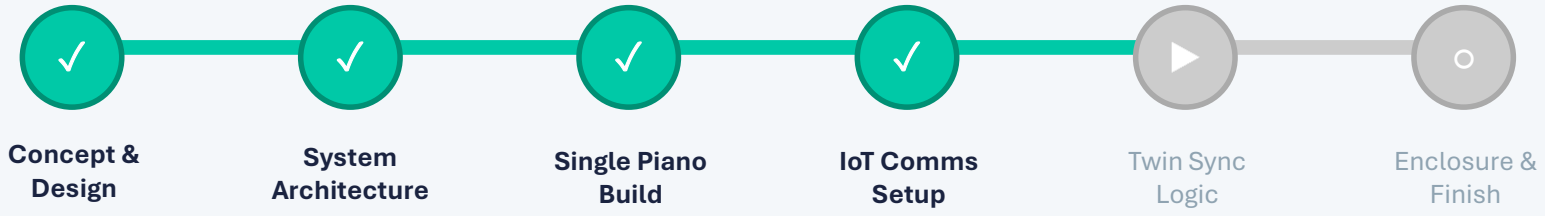
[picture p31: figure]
Concept & Design; System Architecture; Single Piano Build; IoT Comms Setup; Twin Sync Logic; Enclosure & Finish
In Progress / Testing; • Twin synchronisation latency tuning; • Enclosure 3D Printing for both • Battery & power integration; PLAN A

- Solenoid actuator wiring & testing - completed
- Hall sensor / magnet key detection - completed
- Enclosure 3D model (design phase for solenoid)

Finalising and Actively Testing

Solenoid Mechanical Key Sync

- Solenoid plunger physically presses keys on Piano B
- Servo / solenoid wiring tested on breadboard
- Physically mirrors Piano A , visual & tactile sync
- Challenge: latency & power draw being evaluated
- Currently exploring timing calibration

## E N C L O S U R E D E S I G N

M E T H O D FDM 3D Printing; T O O L Autodesk Fusion 360; K E Y S 8-key layout; STAT U S Awaiting print; Melodius_Enclosure_v1.f3d — Fusion 360; Group 6 GPP · MelodiUS · Enclosure · Fusion 360 Design; Print-Ready

Fusion 360 · 3D Model Complete

READY TO PRINT

# TARGET USERS & SCENARIOS


Family Members

Family Connection
Separated by distance, they share a musical moment .A family member plays and another sees and hears the same notes light up in real time.

Long-Distance Couple

Romantic Bond

Partners in different cities share an intimate musical exchange, a melody becomes a love letter sent through sound.

Friends / Pen Pals

Playful Bonding

Two friends rediscover play; no music knowledge needed. Pressing keys together creates spontaneous joy across any distance.

No musical experience required — Melodius is about connection, not performance.

# CHALLENGES & MITIGATIONS

Network Latency

Problem: Real-time solenoid sync is highly sensitive to WiFi jitter , any delay over ~80ms breaks the illusion of simultaneous play.

Mitigation: fallback to LED+sound (Plan B) which tolerates minor delays gracefully.

# NEXT STEPS


This Week

### 1. Finalise solenoid decision

go/no-go by end of sprint

### 2. Confirm Plan B LED+Sound

as reliable demo fallback

### 3. Confirm key notes/melody

### 3. Refine MQTT latency

benchmark over public
internet

### 4. Begin Printing 3D enclosure

for Twin Pianos

### 5. Integrate battery + power

management (sleep modes)

Next 1 Week

### 1. Small user test: emotional

response from non-musicians

### 2. Melodius video shooting

Final Sprint

### 1. Refinement & stability testing

(stress test over distance)

### 2. Polish UX: LED effects, sound

mapping, key feel

3. Demo prep, documentation, and presentation finalisation

Feedback welcome — we are open to suggestions on solenoid vs LED approach and any scope changes.

# M E L O D I U S

## Connecting through Music

# Questions & Feedback

Group 6 GPP · Progress Presentation

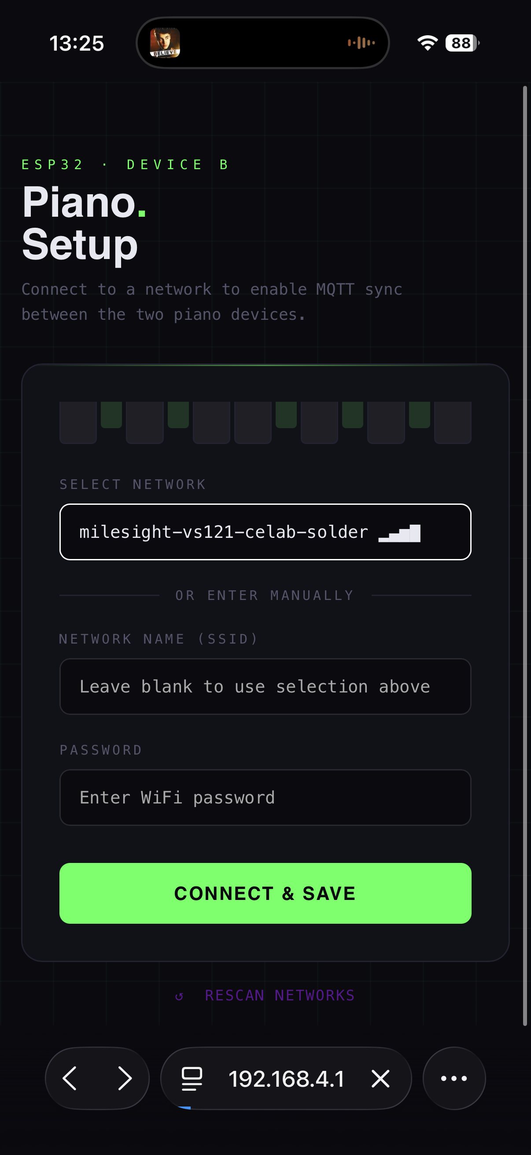
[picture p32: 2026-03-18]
MediaPhotos/hardware_progress/webpage_wifi.PNG

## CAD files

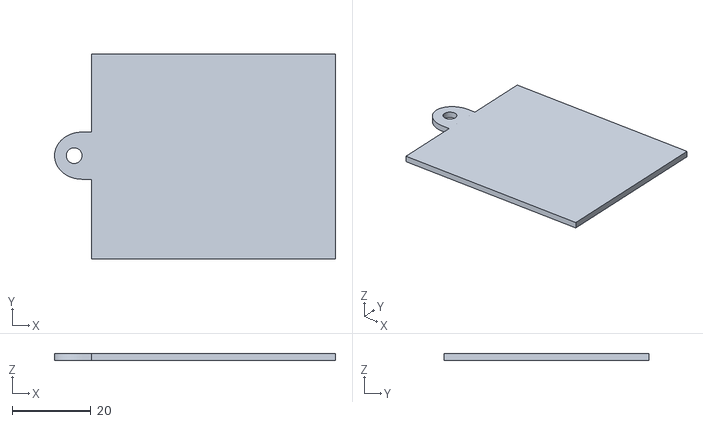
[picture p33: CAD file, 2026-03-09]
Enclosures/bottomCover.stl
71.4 x 52.0 x 1.80

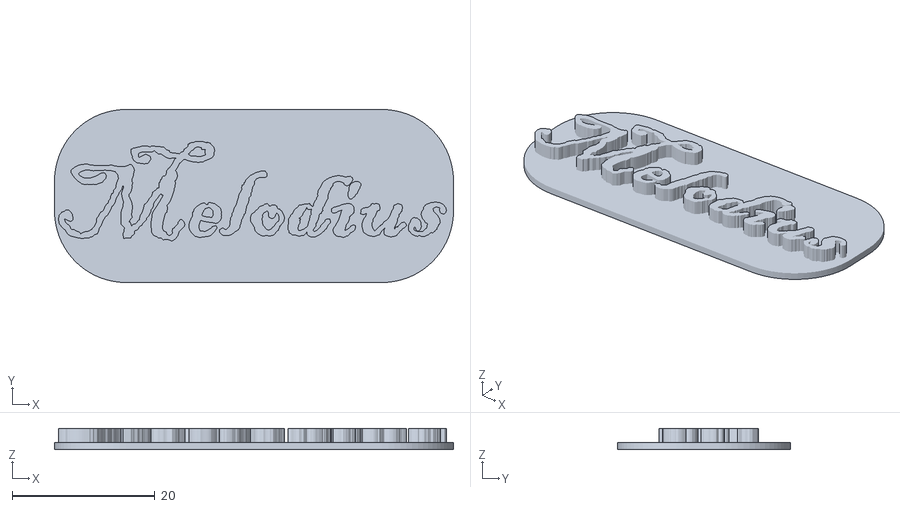
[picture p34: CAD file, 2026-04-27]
Enclosures/final version/logo3.stl
55.8 x 24.2 x 3.00

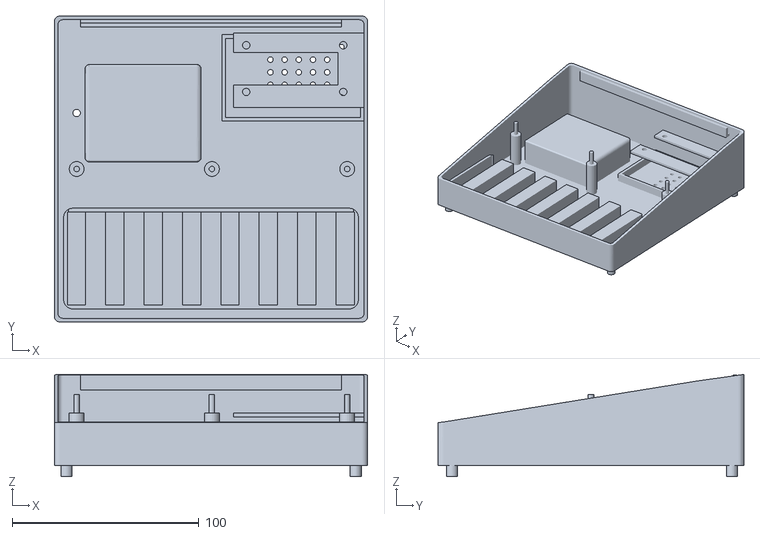
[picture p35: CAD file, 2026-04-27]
Enclosures/final version/bottom.stl
168.0 x 164.0 x 54.7

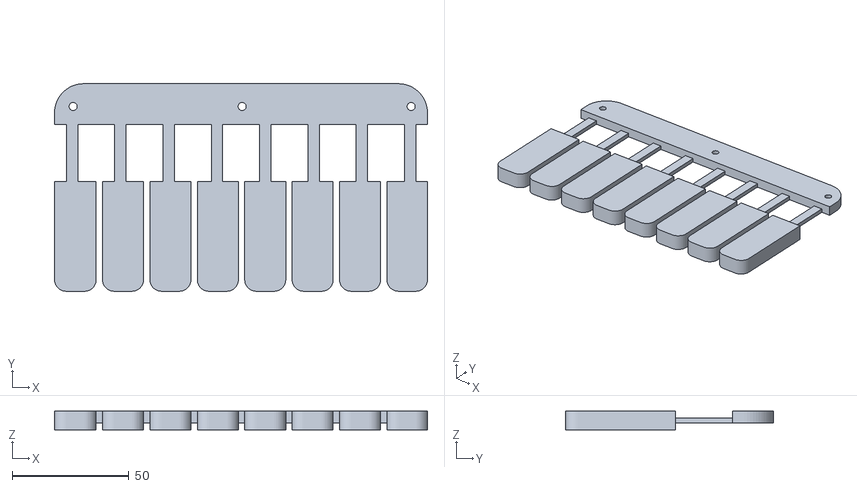
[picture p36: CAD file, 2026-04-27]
Enclosures/final version/Key.stl
160.0 x 89.1 x 8.00

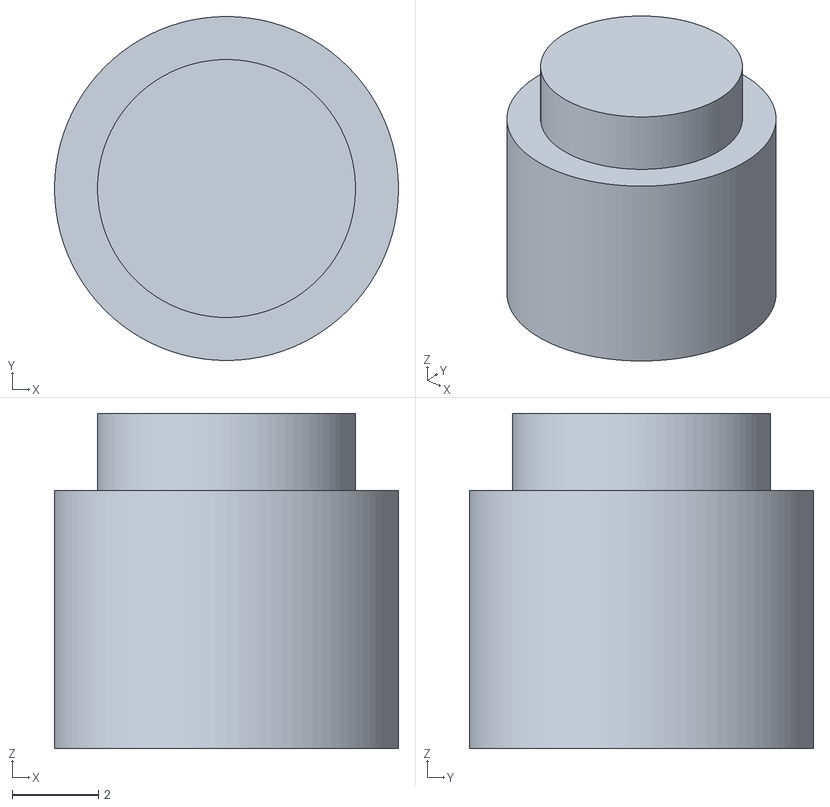
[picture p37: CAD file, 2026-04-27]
Enclosures/final version/pillar.stl
8.00 x 8.00 x 7.80

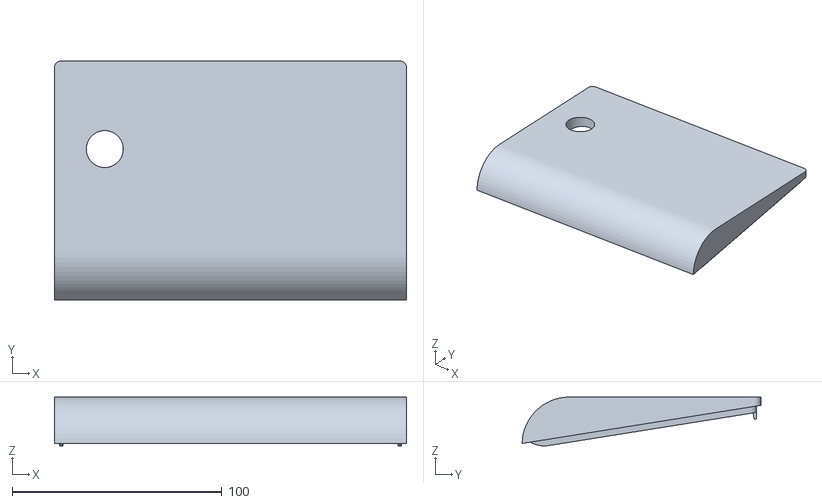
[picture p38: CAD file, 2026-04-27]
Enclosures/final version/Top.stl
168.0 x 114.0 x 23.3

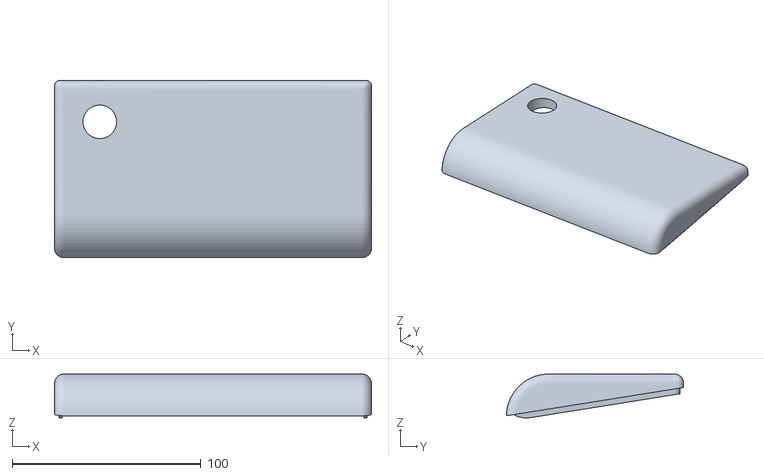
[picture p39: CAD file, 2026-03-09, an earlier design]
Enclosures/Top.stl
168.0 x 94.0 x 23.3

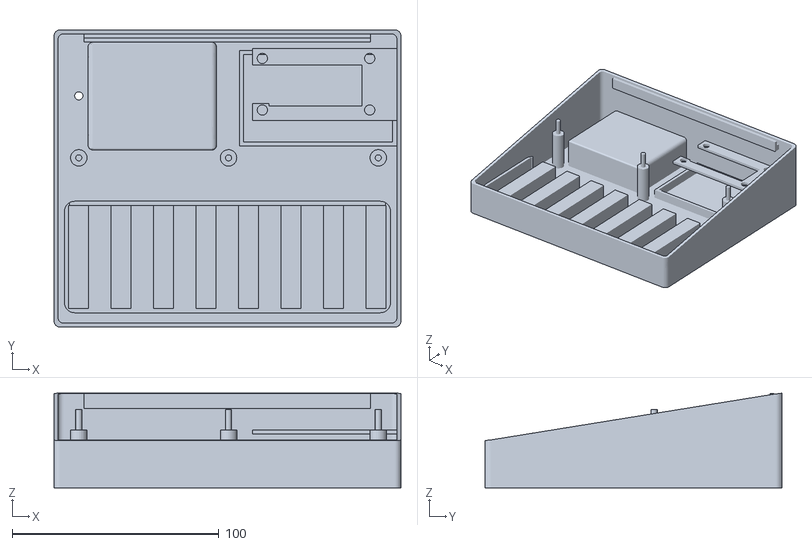
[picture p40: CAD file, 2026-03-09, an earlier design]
Enclosures/bottom.stl
168.0 x 144.0 x 45.9

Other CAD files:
Enclosures/Key.stl

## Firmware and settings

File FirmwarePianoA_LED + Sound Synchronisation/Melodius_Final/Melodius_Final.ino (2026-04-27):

#include <WiFi.h>
#include <WebServer.h>
#include <Preferences.h>
#include <PubSubClient.h>
#include <driver/i2s_std.h>
#include <esp_sleep.h>
#include <esp_task_wdt.h>
#include <esp_wifi.h>
#include <FastLED.h>
#include <math.h>
#include "mqtt_secrets.h"

// ================================================================
//  GLOBAL TYPES / STRUCTS
// ================================================================
typedef struct {
  char cmd;      // 'D' or 'U'
  uint8_t idx;   // 0..7
} MqttEvent;

// ================================================================
//  GLOBAL OBJECTS
// ================================================================
WiFiClient espClient;
PubSubClient mqtt(espClient);
WebServer server(80);
Preferences prefs;
i2s_chan_handle_t tx_handle = NULL;

QueueHandle_t mqttEventQueue = NULL;

// ================================================================
//  HARDWARE CONFIG
// ================================================================
#define USE_WS2812 1

// WS2812
#if USE_WS2812
  #define FASTLED_RMT_MAX_CHANNELS 1
  #define LED_DATA_PIN    16
  #define NUM_LEDS        23
  #define LED_BRIGHTNESS  20
  CRGB leds[NUM_LEDS];

  // 8 keys, each key uses 2 LEDs
  const int KEY_LED_A[8] = {0, 3, 6, 9, 12, 15, 18, 21};
  const int KEY_LED_B[8] = {1, 4, 7, 10, 13, 16, 19, 22};
  const int GAP_LEDS[7]  = {2, 5, 8, 11, 14, 17, 20};
#endif

// MQTT
const char* MQTT_HOST = "mqtt.cetools.org";
const int   MQTT_PORT = 1884;
const char* MQTT_USER = MQTT_USERNAME;
const char* MQTT_PASS = MQTT_PASSWORD;
const char* DEVICE_ID = "B";   // change to "A" on the other board
const char* BASE      = "student/ucfnlwa/0021";

// AP config portal
const char* AP_SSID     = "ESP32-Piano";
const char* AP_PASSWORD = "12345678";

// Button / power
#define POWER_PIN      4
#define LONG_PRESS_MS  3000

// I2S audio
#define I2S_BCLK       18
#define I2S_LRC        19
#define I2S_DOUT       23
#define SAMPLE_RATE    44100
#define BUF_SAMPLES    256

// Keys
const int keyPins[8] = {17, 14, 22, 21, 13, 27, 26, 25};
const unsigned long DEBOUNCE_MS = 20;

// Musical notes C4 -> C5
const float freqs[8] = {262.0, 294.0, 330.0, 349.0, 392.0, 440.0, 494.0, 523.0};

// ================================================================
//  SYSTEM STATE
// ================================================================
String myTopic;
String otherTopic;

volatile bool localOn[8]  = {false};
volatile bool remoteOn[8] = {false};

bool rawLast[8] = {false};
bool stable[8] = {false};
unsigned long lastChangeMs[8] = {0};
float phase[8] = {0};

// Wi-Fi state
String savedSSID = "";
String savedPWD  = "";
bool   hasSavedWiFi = false;
bool   wifiConnecting = false;
unsigned long wifiConnectStart = 0;
unsigned long lastWiFiRetry = 0;

const unsigned long WIFI_CONNECT_TIMEOUT_MS = 12000;
const unsigned long WIFI_RETRY_MS = 5000;

// MQTT state
unsigned long lastMqttRetry = 0;
const unsigned long MQTT_RETRY_MS = 3000;

// Modes
bool configMode = false;

// ================================================================
//  LED ANIMATION STATE
// ================================================================
typedef enum {
  ANIM_NONE,
  ANIM_WIFI_CONNECTING,
  ANIM_CONFIG_MODE,
  ANIM_LONG_PRESS,
  ANIM_RESET_FLASH,
  ANIM_WIFI_SUCCESS,
  ANIM_WIFI_FAIL
} AnimMode;

AnimMode currentAnim = ANIM_NONE;
unsigned long animStart = 0;

// ================================================================
//  FORWARD DECLARATIONS
// ================================================================
void beginWiFiConnect();
bool loadSavedWiFi();
void connectMQTTOnce();
void startConfigMode();
void stopConfigMode();
void enterDeepSleep();
void enqueueMqttEvent(char cmd, int idx);
void clearAllNotes(bool sendRelease = true);

#if USE_WS2812
void setupLEDs();
void updateKeyLEDs();
void updateGapLEDs(unsigned long now);
void showLEDs();
void setAllLEDs(CRGB color);
#endif

// ================================================================
//  LED HELPERS
// ================================================================
#if USE_WS2812

CRGB noteColor(int i) {
  switch (i) {
    case 0: return CRGB(255, 0, 0);
    case 1: return CRGB(255, 80, 0);
    case 2: return CRGB(255, 180, 0);
    case 3: return CRGB(0, 255, 0);
    case 4: return CRGB(0, 255, 180);
    case 5: return CRGB(0, 80, 255);
    case 6: return CRGB(180, 0, 255);
    case 7: return CRGB(255, 255, 255);
  }
  return CRGB::White;
}

void setAllLEDs(CRGB color) {
  for (int i = 0; i < NUM_LEDS; i++) leds[i] = color;
}

void showLEDs() {
  FastLED.show();
}

void setupLEDs() {
  FastLED.addLeds<WS2812, LED_DATA_PIN, GRB>(leds, NUM_LEDS);
  FastLED.setBrightness(LED_BRIGHTNESS);
  setAllLEDs(CRGB::Black);
  showLEDs();
}

void updateKeyLEDs() {
  for (int i = 0; i < 8; i++) {
    CRGB col = (localOn[i] || remoteOn[i]) ? noteColor(i) : CRGB::Black;
    leds[KEY_LED_A[i]] = col;
    leds[KEY_LED_B[i]] = col;
  }
}

void clearGapLEDs() {
  for (int i = 0; i < 7; i++) leds[GAP_LEDS[i]] = CRGB::Black;
}

void updateGapLEDs(unsigned long now) {
  switch (currentAnim) {

    case ANIM_WIFI_CONNECTING: {
      int pos = ((now - animStart) / 120) % 7;
      for (int i = 0; i < 7; i++) {
        leds[GAP_LEDS[i]] = (i == pos) ? CRGB(0, 60, 255) : CRGB::Black;
      }
      break;
    }

    case ANIM_CONFIG_MODE: {
      float t = (float)((now - animStart) % 2000) / 2000.0f;
      float brightness = (sinf(t * 2.0f * M_PI - M_PI / 2.0f) + 1.0f) / 2.0f;
      uint8_t b = (uint8_t)(brightness * 120);
      for (int i = 0; i < 7; i++) leds[GAP_LEDS[i]] = CRGB(0, 0, b);
      break;
    }

    case ANIM_LONG_PRESS: {
      unsigned long elapsed = now - animStart;
      int filled = (int)(elapsed * 7 / LONG_PRESS_MS);
      if (filled > 7) filled = 7;
      for (int i = 0; i < 7; i++) {
        leds[GAP_LEDS[i]] = (i < filled) ? CRGB(255, 0, 0) : CRGB::Black;
      }
      break;
    }

    case ANIM_RESET_FLASH: {
      unsigned long elapsed = now - animStart;
      if (elapsed < 250) {
        setAllLEDs(CRGB(180, 180, 180));
      } else {
        currentAnim = ANIM_CONFIG_MODE;
        animStart = now;
      }
      break;
    }

    case ANIM_WIFI_SUCCESS: {
      if (now - animStart < 350) {
        for (int i = 0; i < 7; i++) leds[GAP_LEDS[i]] = CRGB(0, 255, 80);
      } else {
        currentAnim = configMode ? ANIM_CONFIG_MODE : ANIM_NONE;
        clearGapLEDs();
      }
      break;
    }

    case ANIM_WIFI_FAIL: {
      if (now - animStart < 500) {
        for (int i = 0; i < 7; i++) leds[GAP_LEDS[i]] = CRGB(255, 0, 0);
      } else {
        currentAnim = configMode ? ANIM_CONFIG_MODE : ANIM_NONE;
        clearGapLEDs();
      }
      break;
    }

    case ANIM_NONE:
    default:
      clearGapLEDs();
      break;
  }
}

#endif

// ================================================================
//  AUDIO TASK
// ================================================================
void audioTask(void* param) {
  esp_task_wdt_add(NULL);

  int16_t* buf = (int16_t*)malloc(BUF_SAMPLES * sizeof(int16_t));
  if (!buf) {
    Serial.println("[ERROR] audioTask malloc failed");
    vTaskDelete(NULL);
    return;
  }

  while (true) {
    esp_task_wdt_reset();

    for (int s = 0; s < BUF_SAMPLES; s++) {
      float mix = 0.0f;
      int cnt = 0;

      for (int i = 0; i < 8; i++) {
        if (localOn[i] || remoteOn[i]) {
          mix += sinf(phase[i]);
          phase[i] += 2.0f * (float)M_PI * freqs[i] / (float)SAMPLE_RATE;
          if (phase[i] > 2.0f * (float)M_PI) phase[i] -= 2.0f * (float)M_PI;
          cnt++;
        }
      }

      if (cnt > 0) mix /= (float)cnt;

      // Reduced amplitude for safer power draw
      buf[s] = (int16_t)(mix * 2000);
    }

    size_t written = 0;
    i2s_channel_write(tx_handle, buf, BUF_SAMPLES * sizeof(int16_t), &written, pdMS_TO_TICKS(200));
  }
}

// ================================================================
//  MQTT CALLBACK / TASK
// ================================================================
void mqttCallback(char* topic, byte* payload, unsigned int length) {
  if (String(topic) != otherTopic || length < 2) return;

  char cmd = (char)payload[0];
  int idx = ((char)payload[1]) - '0';

  if (idx < 0 || idx > 7) return;

  Serial.printf("[MQTT] recv %c%d\n", cmd, idx);

  if (cmd == 'D') remoteOn[idx] = true;
  else if (cmd == 'U') remoteOn[idx] = false;
}

void connectMQTTOnce() {
  if (mqtt.connected()) return;

  mqtt.setServer(MQTT_HOST, MQTT_PORT);
  mqtt.setCallback(mqttCallback);

  Serial.print("[MQTT] Connecting...");
  String cid = String("ESP32-") + DEVICE_ID + "-" + String((uint32_t)ESP.getEfuseMac(), HEX);

  bool ok = (strlen(MQTT_USER) > 0)
              ? mqtt.connect(cid.c_str(), MQTT_USER, MQTT_PASS)
              : mqtt.connect(cid.c_str());

  if (ok) {
    Serial.println(" connected!");
    bool subok = mqtt.subscribe(otherTopic.c_str());
    Serial.printf("[MQTT] subscribe %s : %s\n", otherTopic.c_str(), subok ? "OK" : "FAIL");
    for (int i = 0; i < 8; i++) remoteOn[i] = false;
  } else {
    Serial.printf(" failed (rc=%d)\n", mqtt.state());
  }
}

void enqueueMqttEvent(char cmd, int idx) {
  if (mqttEventQueue == NULL) return;

  MqttEvent evt;
  evt.cmd = cmd;
  evt.idx = idx;

  // no blocking in main loop
  xQueueSend(mqttEventQueue, &evt, 0);
}

void mqttTask(void* param) {
  MqttEvent evt;

  for (;;) {
    if (!configMode && WiFi.status() == WL_CONNECTED) {
      if (!mqtt.connected() && millis() - lastMqttRetry > MQTT_RETRY_MS) {
        lastMqttRetry = millis();
        connectMQTTOnce();
      }

      if (mqtt.connected()) {
        mqtt.loop();

        while (xQueueReceive(mqttEventQueue, &evt, 0) == pdTRUE) {
          char msg[3] = {evt.cmd, (char)('0' + evt.idx), '\0'};
          bool ok = mqtt.publish(myTopic.c_str(), msg, false);
          Serial.printf("[MQTT] %s -> %s : %s\n", myTopic.c_str(), msg, ok ? "OK" : "FAIL");
        }
      }
    }

    vTaskDelay(pdMS_TO_TICKS(10));
  }
}

// ================================================================
//  POWER / SLEEP
// ================================================================
void clearAllNotes(bool sendRelease) {
  for (int i = 0; i < 8; i++) {
    bool wasLocal = localOn[i];
    localOn[i] = false;
    remoteOn[i] = false;
    if (sendRelease && wasLocal) {
      enqueueMqttEvent('U', i);
    }
  }
}

void enterDeepSleep() {
  Serial.println("[PWR] Entering deep sleep — press button to wake");

  clearAllNotes(true);
  delay(50);

  if (mqtt.connected()) mqtt.disconnect();
  WiFi.disconnect(true);
  WiFi.mode(WIFI_OFF);

#if USE_WS2812
  setAllLEDs(CRGB::Black);
  showLEDs();
  delay(20);
#endif

  // GPIO4 is RTC-capable on ESP32 classic
  esp_sleep_enable_ext0_wakeup((gpio_num_t)POWER_PIN, 0);
  delay(100);
  esp_deep_sleep_start();
}

void checkPowerButton() {
  static unsigned long pressStart = 0;
  static bool pressing = false;
  static bool longFired = false;

  bool cur = (digitalRead(POWER_PIN) == LOW);
  unsigned long now = millis();

  if (cur && !pressing) {
    pressing = true;
    longFired = false;
    pressStart = now;
    currentAnim = ANIM_LONG_PRESS;
    animStart = now;
    return;
  }

  if (cur && pressing) {
    if (!longFired && (now - pressStart >= LONG_PRESS_MS)) {
      longFired = true;
      Serial.println("[PWR] Long press -> Config mode");
      startConfigMode();
    }
    return;
  }

  if (!cur && pressing) {
    pressing = false;
    unsigned long held = now - pressStart;

    if (held < 30) {
      currentAnim = configMode ? ANIM_CONFIG_MODE : ANIM_NONE;
      return;
    }

    if (!longFired) {
      Serial.println("[PWR] Short press -> Deep sleep");
      enterDeepSleep();
    }
  }
}

// ================================================================
//  WIFI
// ================================================================
bool loadSavedWiFi() {
  prefs.begin("cfg", true);
  savedSSID = prefs.getString("ssid", "");
  savedPWD  = prefs.getString("pwd", "");
  prefs.end();

  hasSavedWiFi = !savedSSID.isEmpty();

  if (hasSavedWiFi) {
    Serial.printf("[WiFi] Saved SSID found: %s\n", savedSSID.c_str());
  } else {
    Serial.println("[WiFi] No saved credentials");
  }

  return hasSavedWiFi;
}

void beginWiFiConnect() {
  if (!hasSavedWiFi || configMode) return;
  if (WiFi.status() == WL_CONNECTED) return;
  if (wifiConnecting) return;

  Serial.printf("[WiFi] Connecting to: %s\n", savedSSID.c_str());

  WiFi.mode(WIFI_STA);
  WiFi.begin(savedSSID.c_str(), savedPWD.c_str());

  wifiConnecting = true;
  wifiConnectStart = millis();
  lastWiFiRetry = millis();

  currentAnim = ANIM_WIFI_CONNECTING;
  animStart = millis();
}

void updateWiFiState() {
  if (configMode) return;

  if (!hasSavedWiFi) {
    startConfigMode();
    return;
  }

  if (WiFi.status() == WL_CONNECTED) {
    if (wifiConnecting) {
      wifiConnecting = false;
      esp_wifi_set_ps(WIFI_PS_NONE);  // reduce latency
      Serial.printf("[WiFi] Connected! IP: %s\n", WiFi.localIP().toString().c_str());
      currentAnim = ANIM_WIFI_SUCCESS;
      animStart = millis();
    }
    return;
  }

  if (!wifiConnecting) {
    if (millis() - lastWiFiRetry > WIFI_RETRY_MS) {
      beginWiFiConnect();
    }
    return;
  }

  if (millis() - wifiConnectStart > WIFI_CONNECT_TIMEOUT_MS) {
    Serial.println("[WiFi] Connection timeout");
    WiFi.disconnect(true);
    wifiConnecting = false;
    currentAnim = ANIM_WIFI_FAIL;
    animStart = millis();
  }
}

// ================================================================
//  CONFIG PORTAL
// ================================================================
String buildPage(String msg = "") {
  int n = WiFi.scanNetworks();
  String options = "";

  for (int i = 0; i < n; i++) {
    String ssid = WiFi.SSID(i);
    String lock = (WiFi.encryptionType(i) == WIFI_AUTH_OPEN) ? "" : "&#128274; ";
    int rssi = WiFi.RSSI(i);
    String bars = rssi > -55 ? "▂▄▆█" : rssi > -70 ? "▂▄▆_" : rssi > -80 ? "▂▄__" : "▂___";
    options += "<option value='" + ssid + "'>" + lock + ssid + "  " + bars + "</option>";
  }
  WiFi.scanDelete();

  String alertHtml = "";
  if (!msg.isEmpty()) {
    bool ok = msg.startsWith("OK") || msg.startsWith("Connected");
    alertHtml = "<div class='alert " + String(ok ? "alert-ok" : "alert-err") + "'>" + msg + "</div>";
  }

  return R"(<!DOCTYPE html>
<html lang="en"><head>
<meta charset="UTF-8"><meta name="viewport" content="width=device-width,initial-scale=1">
<title>Piano Setup</title>
<style>
  :root{--bg:#0a0a0f;--surface:#111118;--border:#222230;--accent:#7fff6e;--accent2:#6e8fff;--text:#e8e8f0;--muted:#55556a}
  *{font-family:'Courier New',Courier,monospace}
  *{box-sizing:border-box;margin:0;padding:0}
  body{background:var(--bg);color:var(--text);min-height:100vh;display:flex;align-items:center;justify-content:center;padding:24px 16px}
  .wrap{width:100%;max-width:420px}
  .header{margin-bottom:28px}
  .header .label{font-size:10px;letter-spacing:4px;text-transform:uppercase;color:var(--accent);margin-bottom:6px}
  .header h1{font-size:32px;font-weight:800;line-height:1}
  .header p{margin-top:8px;font-size:12px;color:var(--muted);line-height:1.6}
  .card{background:var(--surface);border:1px solid var(--border);border-radius:16px;padding:28px;position:relative}
  .field{margin-bottom:20px}
  .field label{display:block;font-size:10px;letter-spacing:2px;text-transform:uppercase;color:var(--muted);margin-bottom:8px}
  select,input[type=text],input[type=password]{width:100%;background:var(--bg);border:1px solid var(--border);border-radius:8px;padding:12px 14px;font-size:13px;color:var(--text)}
  button{width:100%;padding:14px;background:var(--accent);color:#0a0a0f;border:none;border-radius:8px;font-size:14px;font-weight:700;cursor:pointer;margin-top:8px}
  .alert{border-radius:8px;padding:12px 14px;font-size:12px;margin-bottom:20px;border:1px solid}
  .alert-ok{background:rgba(127,255,110,.08);border-color:rgba(127,255,110,.3);color:var(--accent)}
  .alert-err{background:rgba(255,80,80,.08);border-color:rgba(255,80,80,.3);color:#ff6060}
  .divider{display:flex;align-items:center;gap:12px;margin:20px 0;font-size:10px;letter-spacing:2px;color:var(--muted);text-transform:uppercase}
  .divider::before,.divider::after{content:'';flex:1;height:1px;background:var(--border)}
  .legend{margin-top:20px;padding-top:16px;border-top:1px solid var(--border);font-size:11px;color:var(--muted);line-height:2}
  .legend b{color:var(--text)}
</style></head>
<body><div class="wrap">
  <div class="header">
    <div class="label">ESP32 · Device )" + String(DEVICE_ID) + R"(</div>
    <h1>Piano Setup</h1>
    <p>Connect to a network to enable MQTT sync between the two devices.</p>
  </div>
  <div class="card">
    )" + alertHtml + R"(
    <form method="POST" action="/connect">
      <div class="field">
        <label>Select Network</label>
        <select name="ssid">)" + options + R"(</select>
      </div>
      <div class="divider">or enter manually</div>
      <div class="field">
        <label>Network Name (SSID)</label>
        <input type="text" name="manual_ssid" placeholder="Leave blank to use selection above">
      </div>
      <div class="field">
        <label>Password</label>
        <input type="password" name="password" placeholder="Enter WiFi password">
      </div>
      <button type="submit">Connect &amp; Save</button>
    </form>
    <div class="legend">
      <b>Short press</b> — Sleep / Wake<br>
      <b>Hold 3s</b> — Reset WiFi
    </div>
  </div>
</div></body></html>)";
}

void handleRoot() {
  server.sendHeader("Cache-Control", "no-cache");
  server.send(200, "text/html; charset=UTF-8", buildPage());
}

void handleConnect() {
  String ssid = server.arg("manual_ssid");
  if (ssid.isEmpty()) ssid = server.arg("ssid");
  String pwd = server.arg("password");

  if (ssid.isEmpty()) {
    server.send(200, "text/html; charset=UTF-8", buildPage("ERROR: Network name cannot be empty."));
    return;
  }

  server.send(200, "text/html; charset=UTF-8",
    "<html><body style='font-family:Courier New;background:#0a0a0f;color:#e8e8f0;display:flex;align-items:center;justify-content:center;height:100vh;'>"
    "<div style='text-align:center'><h2>Connecting...</h2><p>Please wait up to 15 seconds.</p></div>"
    "</body></html>"
  );

  delay(200);

  WiFi.mode(WIFI_STA);
  WiFi.begin(ssid.c_str(), pwd.c_str());

  unsigned long start = millis();
  while (WiFi.status() != WL_CONNECTED && millis() - start < 15000) {
    delay(200);
  }

  if (WiFi.status() == WL_CONNECTED) {
    Serial.printf("[WiFi] Connected! IP: %s\n", WiFi.localIP().toString().c_str());
    esp_wifi_set_ps(WIFI_PS_NONE);

    prefs.begin("cfg", false);
    prefs.putString("ssid", ssid);
    prefs.putString("pwd", pwd);
    prefs.end();

    savedSSID = ssid;
    savedPWD  = pwd;
    hasSavedWiFi = true;
    wifiConnecting = false;

    stopConfigMode();

#if USE_WS2812
    setAllLEDs(CRGB::Black);
    showLEDs();
#endif
  } else {
    Serial.println("[WiFi] Connection failed");
    WiFi.disconnect();
  }
}

void startConfigMode() {
  configMode = true;
  wifiConnecting = false;

  if (mqtt.connected()) {
    clearAllNotes(true);
    mqtt.disconnect();
  }

  WiFi.disconnect(true);
  WiFi.mode(WIFI_AP_STA);
  WiFi.softAP(AP_SSID, AP_PASSWORD);

  Serial.println("[CONFIG] Hotspot started");
  Serial.printf("[CONFIG] SSID: %s  Pass: %s\n", AP_SSID, AP_PASSWORD);
  Serial.println("[CONFIG] Open: http://192.168.4.1");

  server.on("/", handleRoot);
  server.on("/connect", HTTP_POST, handleConnect);
  server.begin();

  currentAnim = ANIM_RESET_FLASH;
  animStart = millis();
}

void stopConfigMode() {
  server.stop();
  configMode = false;
  WiFi.softAPdisconnect(true);
  currentAnim = ANIM_NONE;
  lastWiFiRetry = 0;
}
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
void loop() {
  checkPowerButton();

  if (configMode) {
    server.handleClient();

  #if USE_WS2812
    static unsigned long lastLEDcfg = 0;
    unsigned long nowCfg = millis();
    if (nowCfg - lastLEDcfg > 30) {
      lastLEDcfg = nowCfg;
      updateKeyLEDs();
      updateGapLEDs(nowCfg);
      showLEDs();
    }
  #endif
    return;
  }

  updateWiFiState();

  // Key scan
  unsigned long now = millis();
  for (int i = 0; i < 8; i++) {
    bool raw = (digitalRead(keyPins[i]) == LOW);

    if (raw != rawLast[i]) {
      rawLast[i] = raw;
      lastChangeMs[i] = now;
    }

    if ((now - lastChangeMs[i]) > DEBOUNCE_MS && stable[i] != raw) {
      stable[i] = raw;
      localOn[i] = raw;
      enqueueMqttEvent(raw ? 'D' : 'U', i);
      Serial.printf("[KEY] key%d %s (GPIO%d)\n", i + 1, raw ? "DOWN" : "UP", keyPins[i]);
    }
  }

#if USE_WS2812
  static unsigned long lastLED = 0;
  if (now - lastLED > 30) {
    lastLED = now;
    updateKeyLEDs();
    updateGapLEDs(now);
    showLEDs();
  }
#endif
}

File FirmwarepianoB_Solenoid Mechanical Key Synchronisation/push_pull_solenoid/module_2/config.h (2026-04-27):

// MODULE_2

#pragma once

// ── Sensors & actuators ───────────────────────────────────
const int NUM_SENSORS        = 2;
const int hallPins[]         = {9, 21};
const int solenoidPins[]     = {17, 18};
#define   RESET_PIN            4

// ── Solenoid timing ───────────────────────────────────────
#define SOLENOID_DURATION      500   // ms — coil on-time per trigger

// ── I²S pins (MAX98357A) ──────────────────────────────────
#define I2S_BCLK               26
#define I2S_LRCK               25
#define I2S_DIN                22
#define I2S_PORT               I2S_NUM_0   // passed to i2s_new_channel only

// ── Audio quality ─────────────────────────────────────────
#define SAMPLE_RATE            44100
#define AMPLITUDE              6000  // 0–32767 — sets volume

// ── Melody timing ─────────────────────────────────────────
#define NOTE_DURATION_MS       300   // ms per note before advancing

// ── MQTT broker ───────────────────────────────────────────
#define MQTT_SERVER            "mqtt.cetools.org"
#define MQTT_PORT              1884

// ── Module identity — swap comments for Module 2 ─────────
#define WIFI_AP_NAME           "ESP32-Module2"   // "ESP32-Module2"
#define MQTT_CLIENT_ID         "module2"          // "module2"
#define MQTT_TOPIC_PUB         "student/ucfnake/solenoid/trigger_module_2"
#define MQTT_TOPIC_SUB         "student/ucfnake/solenoid/trigger_module_1"

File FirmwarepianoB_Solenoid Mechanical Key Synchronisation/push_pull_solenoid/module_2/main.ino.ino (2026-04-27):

// MODULE_2

// #include <Arduino.h>
// #include <WiFiManager.h>
// #include <WiFi.h>

// #include "config.h"
// #include "audio.h"
// #include "melody.h"
// #include "mqtt.h"
// #include "solenoid.h"
// #include "lights.h"

// // ── Internal state ────────────────────────────────────────
// static bool lastHallState[NUM_SENSORS];
// static bool wifiWasConnected = false;

// // ─────────────────────────────────────────────────────────
// // Wi-Fi captive-portal onboarding
// // ─────────────────────────────────────────────────────────
// static void startWiFi() {
//   WiFiManager wm;
//   // wm.resetSettings();  // uncomment once to clear saved credentials
//   wm.setConfigPortalTimeout(180);
//   wm.setConnectTimeout(20);
//   Serial.println("[WiFi] Starting...");
//   if (!wm.autoConnect(WIFI_AP_NAME)) {
//     Serial.println("[WiFi] Portal timed out — restarting");
//     ESP.restart();
//   }
//   Serial.printf("[WiFi] Connected! IP: %s\n", WiFi.localIP().toString().c_str());
// }

// // ─────────────────────────────────────────────────────────
// // Hold RESET_PIN LOW for 3 s to wipe Wi-Fi credentials
// // ─────────────────────────────────────────────────────────
// static void checkResetButton() {
//   if (digitalRead(RESET_PIN) == LOW) {
//     unsigned long held = millis();
//     Serial.println("[Reset] Button held...");
//     while (digitalRead(RESET_PIN) == LOW) {
//       if (millis() - held > 3000) {
//         Serial.println("[Reset] Wiping WiFi credentials — restarting");
//         WiFiManager wm;
//         wm.resetSettings();
//         ESP.restart();
//       }
//     }
//   }
// }

// // ─────────────────────────────────────────────────────────
// void setup() {
//   Serial.begin(115200);

//   pinMode(RESET_PIN, INPUT_PULLUP);

//   for (int i = 0; i < NUM_SENSORS; i++) {
//     pinMode(hallPins[i],     INPUT_PULLUP);
//     pinMode(solenoidPins[i], OUTPUT);
//     digitalWrite(solenoidPins[i], LOW);
//     lastHallState[i] = HIGH;
//   }

//   lightsSetup();          // dim red — before Wi-Fi attempt
//   i2sInit();
//   solenoidSetup();        // create esp_timer handles for solenoid cutoff
//   startWiFi();
//   setLedState(LED_WIFI_CONNECTED);  // green once connected
//   wifiWasConnected = true;
//   mqttSetup();
// }

// // ─────────────────────────────────────────────────────────
// void loop() {
//   checkResetButton();

//   // Wi-Fi watchdog
//   if (WiFi.status() != WL_CONNECTED) {
//     Serial.println("[WiFi] Lost — reconnecting");
//     WiFi.reconnect();
//     delay(5000);
//     return;
//   }

//   // Wi-Fi watchdog
//   if (WiFi.status() != WL_CONNECTED) {
//     if (wifiWasConnected) {
//       setLedState(LED_WIFI_DISCONNECTED);  // back to dim red
//       wifiWasConnected = false;
//     }
//     Serial.println("[WiFi] Lost — reconnecting");
//     WiFi.reconnect();
//     delay(5000);
//     return;
//   }

//   // Restore green if Wi-Fi just came back
//   if (!wifiWasConnected) {
//     setLedState(LED_WIFI_CONNECTED);
//     wifiWasConnected = true;
//   }

//   reconnectMQTT();
//   mqttLoop();
//   updateSolenoids();
//   updateSound();

//   // Hall sensor edge detection + LED colour per melody
//   for (int i = 0; i < NUM_SENSORS; i++) {
//     bool current = digitalRead(hallPins[i]);

//     if (current == LOW && lastHallState[i] == HIGH) {
//       hallSoundRequest[i] = true;
//       sendSensorIndex(i);
//       // Light up the colour for this sensor's melody
//       setLedState(i == 0 ? LED_MELODY_0 : LED_MELODY_1);
//     }
//     if (current == HIGH && lastHallState[i] == LOW) {
//       hallSoundRequest[i] = false;
//       // Return to idle green if no other sensor is still held
//       bool anyActive = false;
//       for (int j = 0; j < NUM_SENSORS; j++) {
//         if (hallSoundRequest[j] || solenoidSoundRequest[j]) { anyActive = true; break; }
//       }
//       if (!anyActive) setLedState(LED_WIFI_CONNECTED);
//     }

//     lastHallState[i] = current;
//   }

//   delay(20);
// }

#include <Arduino.h>
#include <WiFiManager.h>
#include <WiFi.h>

#include "config.h"
#include "audio.h"
#include "melody.h"
#include "mqtt.h"
#include "solenoid.h"
#include "lights.h"

// ── Internal state ────────────────────────────────────────
static bool lastHallState[NUM_SENSORS];
static bool wifiWasConnected = false;

// ─────────────────────────────────────────────────────────
// Wi-Fi captive-portal onboarding
// ─────────────────────────────────────────────────────────
static void startWiFi() {
  WiFiManager wm;
  // wm.resetSettings();  // uncomment once to clear saved credentials
  wm.setConfigPortalTimeout(180);
  wm.setConnectTimeout(20);
  Serial.println("[WiFi] Starting...");
  if (!wm.autoConnect(WIFI_AP_NAME)) {
    Serial.println("[WiFi] Portal timed out — restarting");
    ESP.restart();
  }
  Serial.printf("[WiFi] Connected! IP: %s\n", WiFi.localIP().toString().c_str());
}

// ─────────────────────────────────────────────────────────
// Hold RESET_PIN LOW for 3 s to wipe Wi-Fi credentials
// ─────────────────────────────────────────────────────────
static void checkResetButton() {
  if (digitalRead(RESET_PIN) == LOW) {
    unsigned long held = millis();
    Serial.println("[Reset] Button held...");
    while (digitalRead(RESET_PIN) == LOW) {
      if (millis() - held > 3000) {
        Serial.println("[Reset] Wiping WiFi credentials — restarting");
        WiFiManager wm;
        wm.resetSettings();
        ESP.restart();
      }
    }
  }
}

// ─────────────────────────────────────────────────────────
void setup() {
  Serial.begin(115200);

  pinMode(RESET_PIN, INPUT_PULLUP);

  for (int i = 0; i < NUM_SENSORS; i++) {
    pinMode(hallPins[i],     INPUT_PULLUP);
    pinMode(solenoidPins[i], OUTPUT);
    digitalWrite(solenoidPins[i], LOW);
    lastHallState[i] = HIGH;
  }

  lightsSetup();          // dim red — before Wi-Fi attempt
  i2sInit();
  startWiFi();
  setLedState(LED_WIFI_CONNECTED);  // green once connected
  wifiWasConnected = true;
  mqttSetup();
}
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

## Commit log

2026-03-13 MelodiUS Twin Piano Project
    [Key.stl, Top.stl, bottom.stl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]
2026-03-18 Add ESP32 piano firmware v1.0 and v2.0
    Add initial firmware for an ESP32-based piano project and a more advanced v2.0. Commits: add .gitignore (ignore *.h) and two firmware files.
    version1.0: simple MQTT-enabled demo (LED + buzzer) with WiFi/MQTT integration, topic-based pressed state sync, and commented alternate I2S/polyphonic synth code.
    version2.0: full-featured firmware with I2S audio task, PubSub MQTT integration, WebServer AP-based WiFi configuration (Preferences), WS2812 LED support via FastLED, power button handling, debounced 8-key scanning, tasked audio generation, and improved MQTT/topic handling and reconnection logic.
    [version1.0.ino, version2.0.ino]
2026-03-18 Add ESP32 piano firmware with LEDs/MQTT
    Add complete ESP32 sketch implementing a two-board synced piano: WS2812 LED support (FastLED), I2S audio generation, MQTT-based note sync, and a web config AP for WiFi credentials. Features include debounced key handling, local/remote note state, publish/subscribe events, persistent credentials via Preferences, power-button handling (short toggle / long-press to open config), and LED animations for status (connecting, config, long-press, success/fail). Audio runs on a pinned task using i2s; MQTT topics and device ID are configurable. Designed to run as device "A" (change DEVICE_ID for the other board).
    [ESP32_Piano_final.ino]
2026-03-18 Add hardware progress media files
    Add photos and videos documenting hardware development under MediaPhotos and MediaVideos/hardware_progress (FinalDevice, key+buzzer+rgb, keys+speaker, webpage WiFi, etc.) These assets provide visual records for v1.0–v3.0 iterations of the device.
2026-03-23 Create device
2026-04-27 Add Melodius_Final.ino and move ESP32_Piano_final
    Add a new Melodius_Final.ino sketch implementing an ESP32 piano: I2S audio synthesis for 8 notes, WS2812 LED support and animations, MQTT sync between two devices, a Wi‑Fi config portal (AP mode + we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
